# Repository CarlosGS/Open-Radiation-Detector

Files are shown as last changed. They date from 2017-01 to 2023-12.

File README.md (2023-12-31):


# Open Radiation Detector
Portable radiation detector based on a ionization chamber.

The KiCad PCB sources and BOM can be found in the repository's subfolders.

Check out <https://hackaday.io/project/27508-open-radiation-detector> for more information.

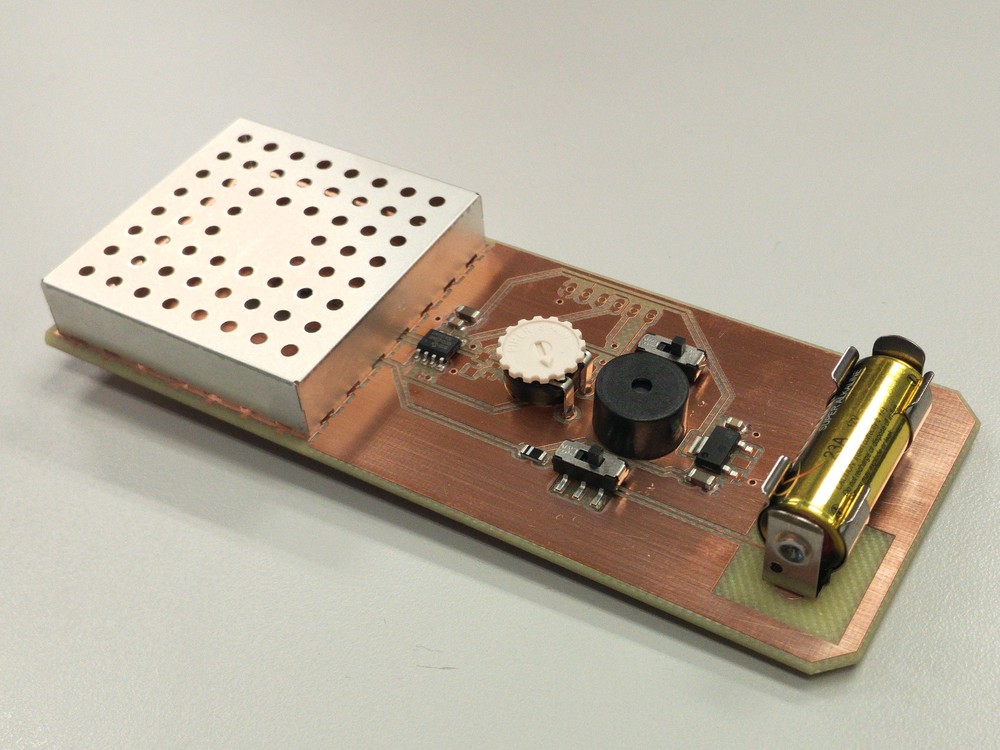
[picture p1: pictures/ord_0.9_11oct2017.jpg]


# Next version:
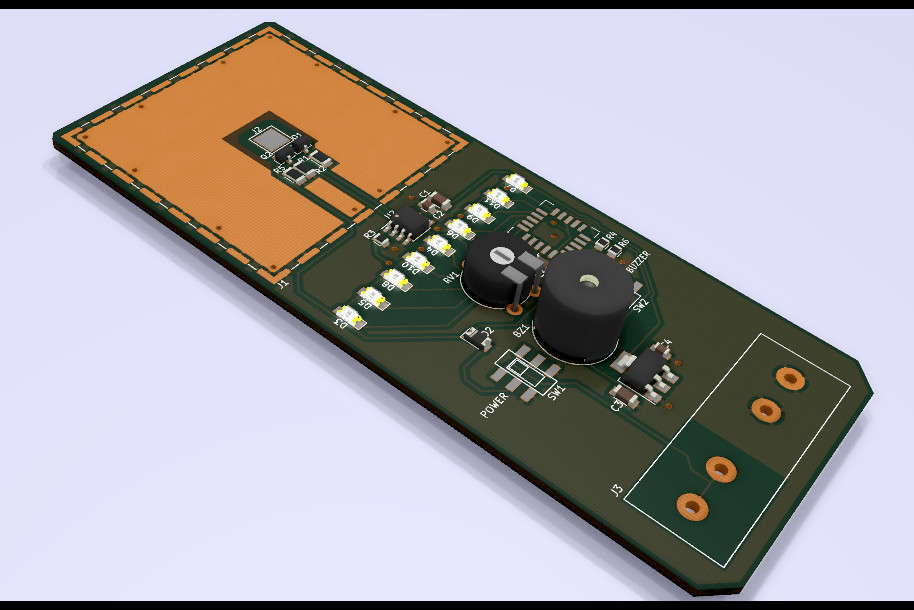
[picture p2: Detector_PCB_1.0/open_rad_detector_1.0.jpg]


# The detector works!
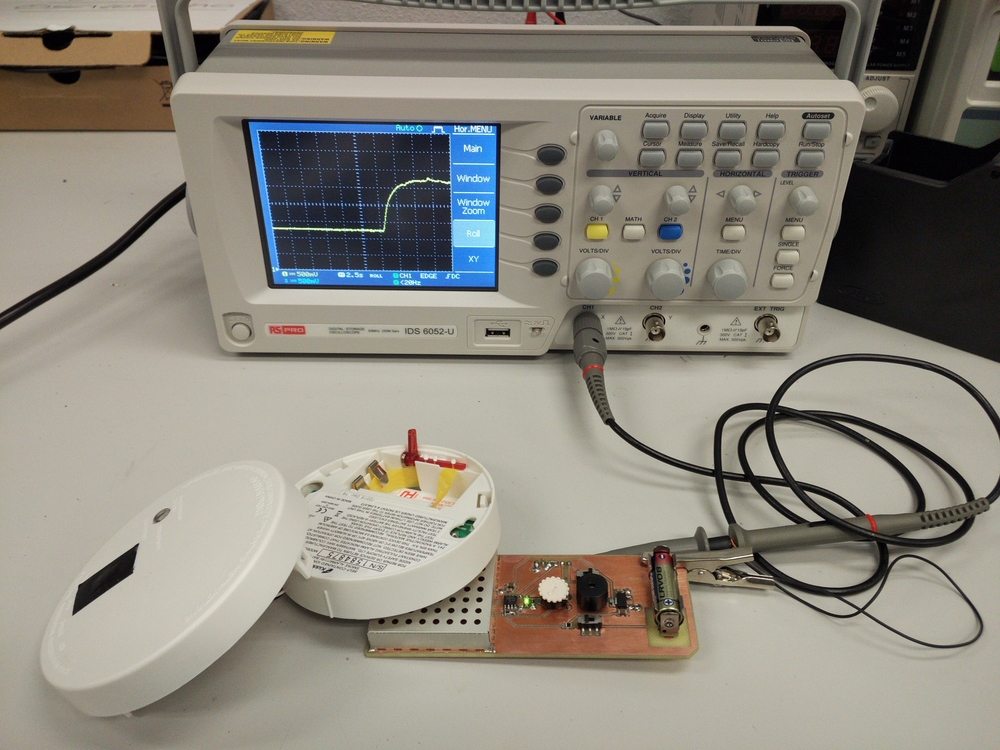
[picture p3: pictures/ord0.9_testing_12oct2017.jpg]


Progress
--
- October 2017: Designed, build and document a prototype to participate in the Hackaday Prize.

- 5/May/2017: The radiation sensor concept has been incorporated into a connected sensor board. It looks like the effect of nearby electrostatic fields still affects the voltage output, regardless of the back plane being connected to either guard voltage or ground (maybe this is due to the large size of the electrode?). The board uses the PNP configuration polarized with 10 MOhm 1% and an op-amp driver (LM2904DR) to minimize the effect of ADC current consumption. It includes a duplicate circuit unconnected from the electrode, to be used as a compensation for temperature effects.

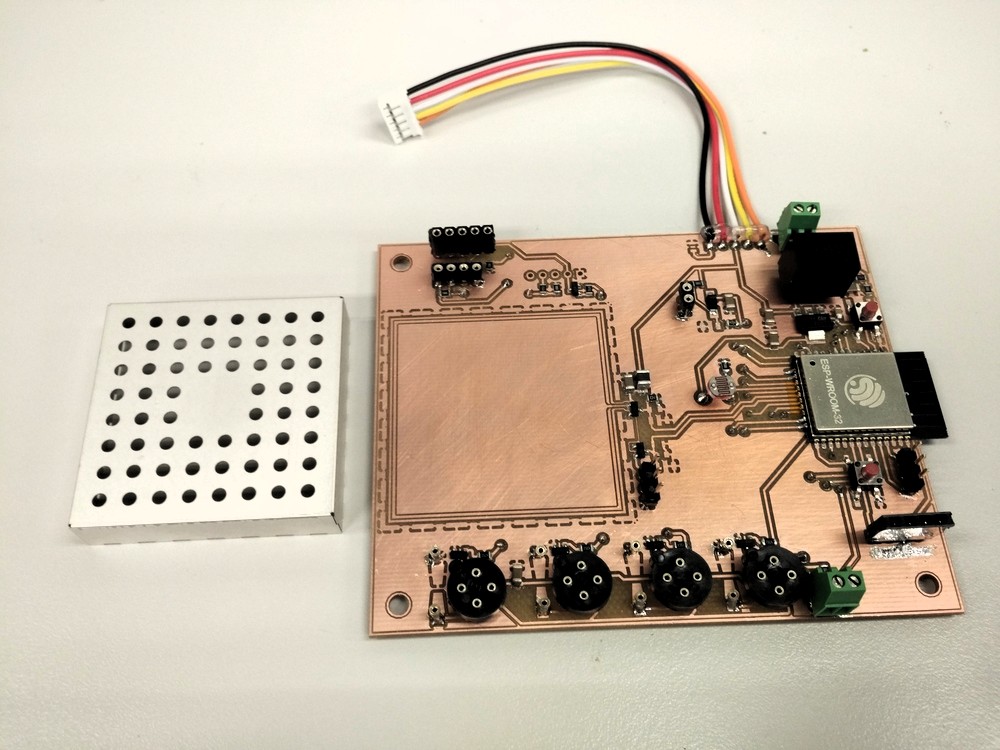
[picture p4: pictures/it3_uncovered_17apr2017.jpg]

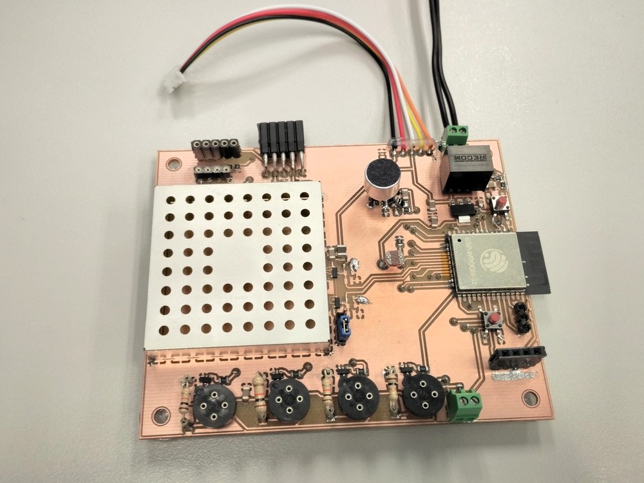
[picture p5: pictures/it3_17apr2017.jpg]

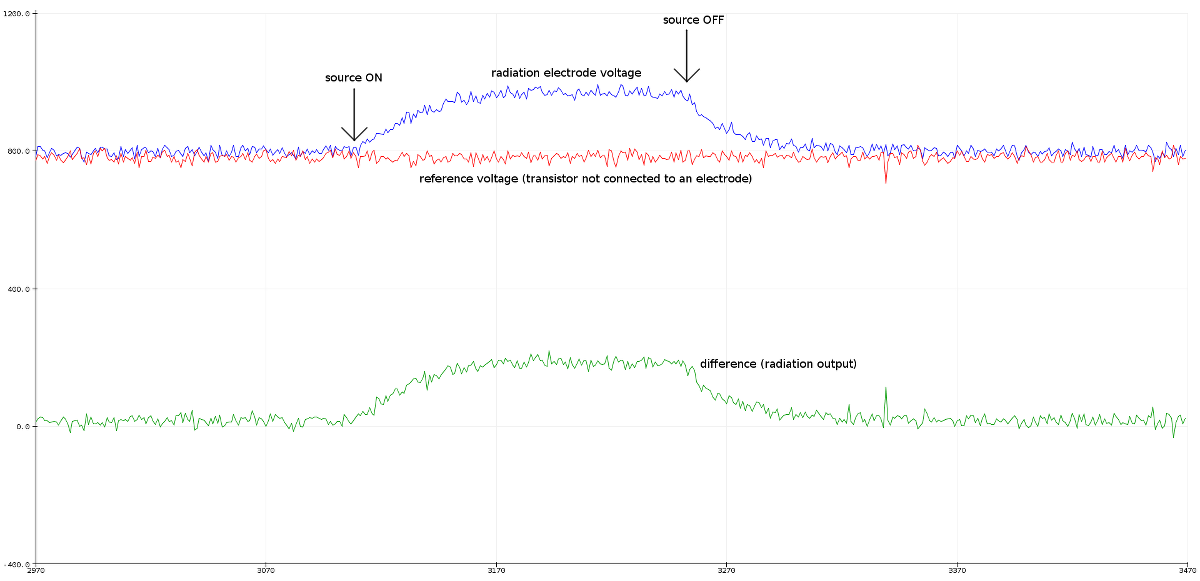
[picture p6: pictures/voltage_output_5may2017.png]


- 15/Feb/2017: It works! At first the result with the new transistors had lots of noise as well. But adding a copper plane behind the main electrode seems to have done the trick. So maybe the transistors were not the problem after all! The pictures show a new prototype being tested with and without a radiation source. Its response ranges from 70mV to 160mV and it is way more stable than before. Schematic is [Charles Wenzel's Experimenters Ionization Chamber](http://www.techlib.com/science/ion.html#Experimenters%20Chamber) with an FMMT634TA NPN darlington transistor.

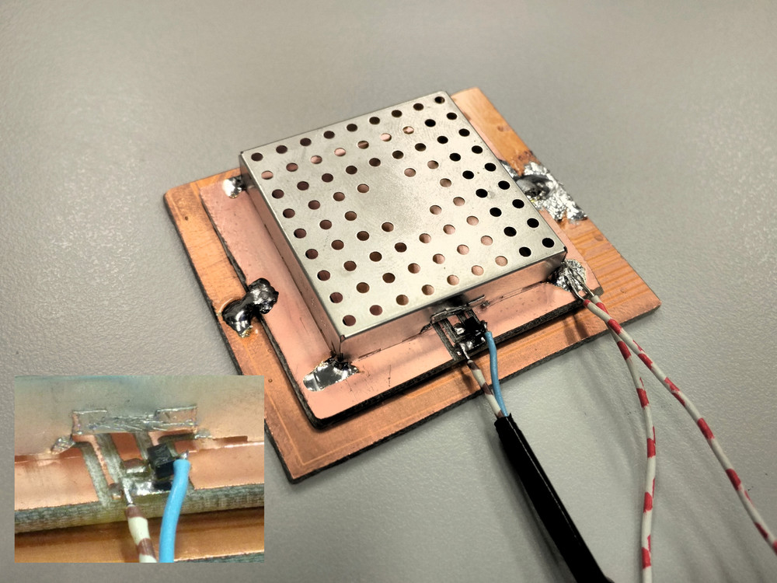
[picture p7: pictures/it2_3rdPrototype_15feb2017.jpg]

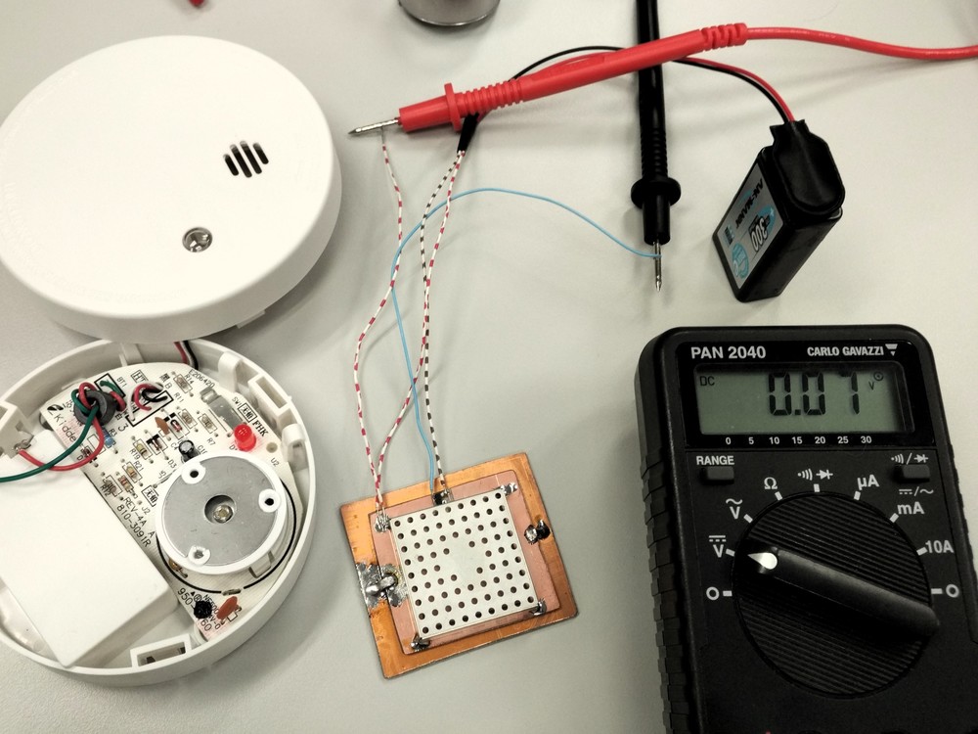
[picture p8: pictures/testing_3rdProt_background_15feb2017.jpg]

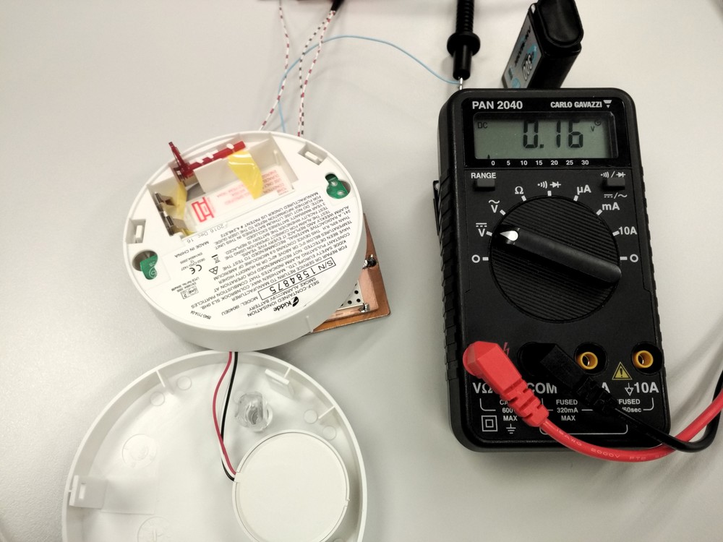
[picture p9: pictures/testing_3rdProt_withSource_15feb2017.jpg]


- 8/Feb/2017: The Darlington transistors used until now (MMBT6427, MMBTA14, MMBTA28, MMBTA63, MMBTA64) may not be suitable for detecting the low currents involved in this detection problem (nA or even pA). Yet again I have resorted to Charles Wenzel's awesome website. A proper surface-mount alternative to the MPSAW45A power darlington transistor may be the FMMT634 and FMMT734. So I've ordered a bunch of these transistors in order to test the concept again.

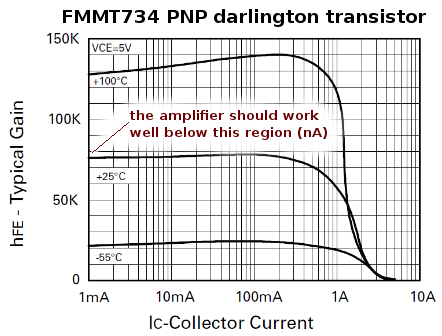
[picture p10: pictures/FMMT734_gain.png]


- Week of 7/Feb/2017: The new approach is to use an actual ion chamber that uses a copper electrode insulated from ground by an outer guard ring. The chamber itself is made of [a standard size, commercially available PCB shielding can](http://www.mouser.es/Search/ProductDetail.aspx?R=BMI-S-104virtualkey64820000virtualkey739-BMI-S-104) (in the pictures you can see my attempt at creating one with tin sheet from a metal can). The first prototype actually seemed to have some reaction during the tests. However the second prototype did not. [G-code to mill the electrode](http://jscut.org/jscut.html?gist=c962737e35c9f9b0445b82d079ceb10d).

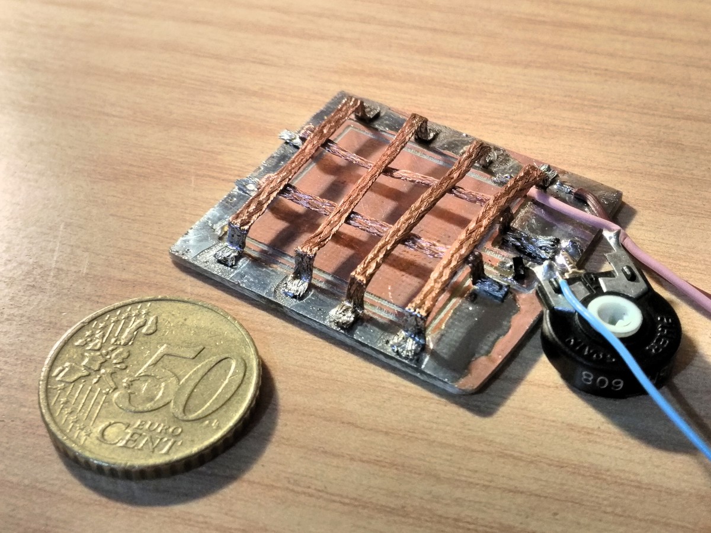
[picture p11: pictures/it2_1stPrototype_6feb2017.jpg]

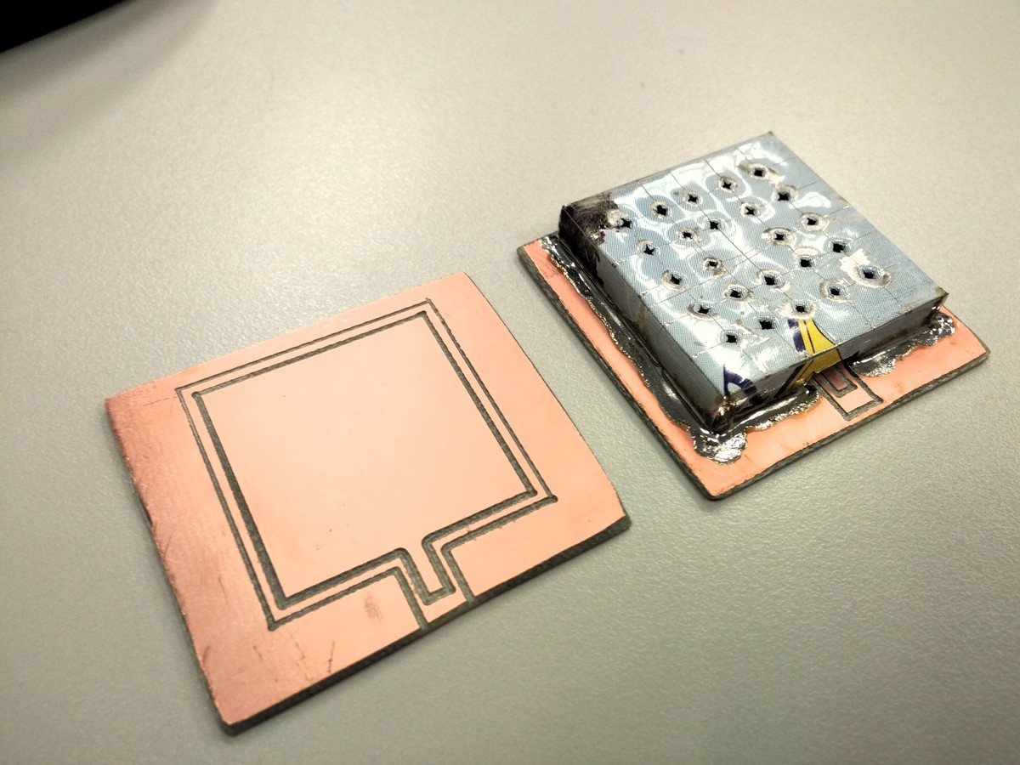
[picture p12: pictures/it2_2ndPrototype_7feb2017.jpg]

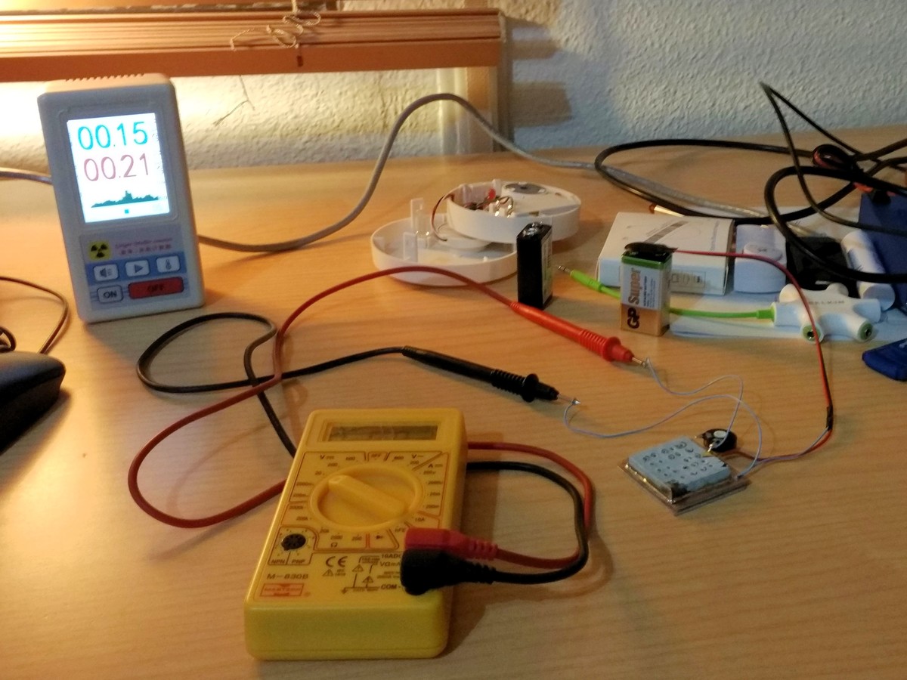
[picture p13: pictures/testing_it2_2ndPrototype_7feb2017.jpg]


- On a second thought, the "finger electrodes" may not be a good idea. Since there is a large contact area between each finger, there surely is a lot of leakage current that will mask-out any ion-induced current (one of the biggest concerns explained by [Charles Wenzel's ion chamber website](http://www.techlib.com/science/ion.html))

- 19/Jan/2017 Finally got a .9uCi AM241 source to test, it will be the benchmark for the detector. Unfortunately, the first attempts with the amplifier circuit yield very noisy measurements, that mainly depend on wind and humidity. Surprisingly (to me), it is also very dependent on static electricity. I've also tested again the spark particle detector, but there seems to be absolutely no relation between the sparks and the proximity of the radiation source. Maybe the finger electrodes are too "pointy" because of the manufacture method (milling)? [pic1](pictures/fingerElectrodeZoom1_19Jan2017.jpg) [pic2](pictures/fingerElectrodeZoom2_19Jan2017.jpg)

- Week of 9/Jan/2017: Simulation of circuit amplifiers ["click type"](http://lushprojects.com/circuitjs/circuitjs.html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), ["LED scale type"](http://lushprojects.com/circuitjs/circuitjs.html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)

- Self-ask the question: How to make a simple low-cost radiation detector? Begin to learn about ionization chambers thanks to [Charles Wenzel's website](http://www.techlib.com/science/ion.html).

- Week of 1/Jan/2017: First learn of spark particle detectors. [Design, build and test a PCB electrode](https://github.com/vlachoudis/bCNC/pull/480) (but without any radiation source to be tested). [video](https://www.youtube.com/watch?v=s3N2EDGwe9U)

# License
This work is licensed under a Creative Commons Attribution 4.0 International License.
<https://creativecommons.org/licenses/by/4.0/>

Please cite as:
--
Garcia-Saura, C. (2017). Open Radiation Detector. GitHub. https://doi.org/10.5281/ZENODO.10446305

Latex / Bibtex citation:
```bibtex
@misc{garciasaura2017rad,
  author = {Garcia-Saura, Carlos},
  title = {Open Radiation Detector},
  publisher = {GitHub},
  year = {2017},
  doi = {10.5281/ZENODO.10446305},
  url = {https://doi.org/10.5281/ZENODO.10446305}
}
```

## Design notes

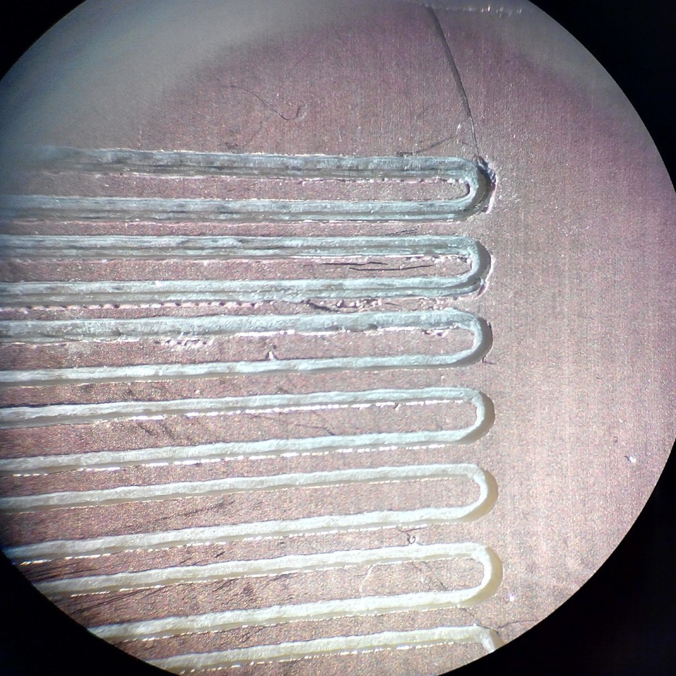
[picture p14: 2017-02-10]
pictures/fingerElectrodeZoom2_19Jan2017.jpg

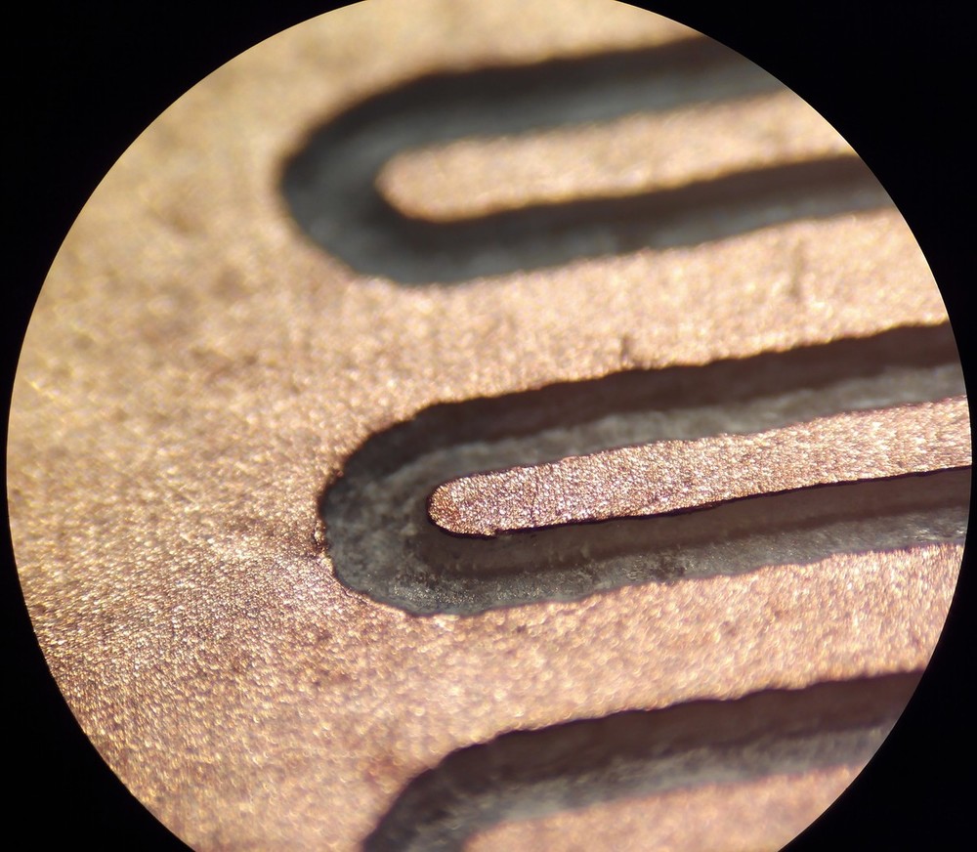
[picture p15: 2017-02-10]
pictures/fingerElectrodeZoom1_19Jan2017.jpg

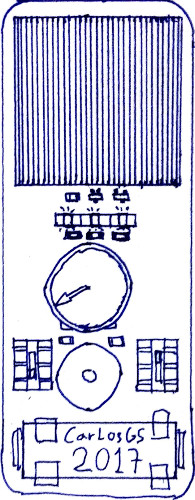
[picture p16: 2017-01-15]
pictures/ORD_sketch_15jan2017.jpg

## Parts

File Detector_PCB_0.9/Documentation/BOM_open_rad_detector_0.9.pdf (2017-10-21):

open_rad_detector

Page 1

Source | open-radiation-detector/Detector_PCB_0.9/open_rad_detector.sch
Title | Open Radiation Detector
Revision | 0,9
Author: Carlos Garcia Saura
License: Creative Commons Attribution-ShareAlike 4.0 International
https://creativecommons.org/licenses/by-sa/4.0/
https://hackaday.io/project/27508-open-radiation-detector/ | Total cost: | 14 | € | (bulk would be cheaper)
Reference | Value | Library | Library Ref | Manufacturer | Product ID | Provider | €/pc (17 oct 2017)
J1 | Outer_Shield | device | RF_Shield_One_Piece | Laird | BMI-S-107 | 3,9
BZ1 | Buzzer | device | Buzzer | Buzzer is not working yet. Please wait for the next version. | 1 | (link pending)
C1 | 10u | device | C | Vishay | VJ1206V106ZXQTW1B | 0,085 | (any other compatible is OK)
C2 | 100n | device | C | Vishay | VJ0805Y104JXXAC | 0,085 | (any other compatible is OK)
C3 | 10u | device | C | Vishay | VJ1206V106ZXQTW1B | 0,085 | (any other compatible is OK)
C4 | 100n | device | C | Vishay | VJ0805Y104JXXAC | 0,085 | (any other compatible is OK)
D1 | LED | device | LED | Lite-On | LTST-C150GKT | 0,315 | (any other compatible is OK)
D2 | D | device | D | AVX | SD1206S040S0R5 | 0,349 | (any other compatible is OK)
J2 | Electrode | conn | CONN_01X01 | AVX | 709176001511006 | 0,179 | Another option: | Mill-Max | 1944-0-00-15-00-00-03-0
J3 | Batt | conn | CONN_01X02 | Keystone Electronics | 82 | 0,76 | Need to buy 2 (two)
J4 | CONN_01X06 | conn | CONN_01X06 | Any connector of your choice
Q1 | FMMT734 | transistors | BC858 | Diodes Incorporated | FMMT734 | 0,476
Q2 | FMMT734 | transistors | BC858 | Diodes Incorporated | FMMT735 | 0,476
R1 | 10M | device | R | Vishay | CRCW120610M0FKEA | 0,085 | (any other compatible is OK)
R2 | 10M | device | R | Vishay | CRCW120610M0FKEA | 0,085 | (any other compatible is OK)
R3 | R_G | device | R | Vishay | CRCW08051K00FKEA | 0,085 | (any other compatible is OK)
R4 | R_LED | device | R | Vishay | CRCW0805330RFKEB | 0,085 | (any other compatible is OK)
R5 | 10M | device | R | Vishay | CRCW120610M0FKEA | 0,085 | (any other compatible is OK)
RV1 | R_F | device | POT | Piher | PT10MV10-104A2020 | 0,518
RV1 knob | Plastic knob for RV1 potentiometer | Piher | XBOPL5034CR | 0,227 | Hand mounted on potentiometer
SW1 | POWER | switches | SW_SPDT | C&K Components | JS202011SCQN | 0,374
SW2 | BUZZER | switches | SW_SPDT | C&K Components | JS202011SCQN | 0,374
U1 | LD1117S50TR | regul | LD1117S50TR | STMicroelectronics | LD1117S50TR | 0,383
U2 | MCP6N11 | MCP6N11 | MCP6N11 | Microchip Technology | MCP6N11-010E/SN | 1,26
Battery | Any A23 battery (12V), widely available in many stores | 2

http://www.mouser.es/ProductDetail/Laird/BMI-S-107/?qs=5UmOb8GQ3yLqc%2FnmGxIDzQ%3D%3D

http://www.mouser.es/ProductDetail/Vishay-Vitramon/VJ1206V106ZXQTW1BC/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 http://www.mouser.es/Search/ProductDetail.aspx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

http://www.mouser.es/ProductDetail/Diodes-Incorporated/FMMT734TA/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

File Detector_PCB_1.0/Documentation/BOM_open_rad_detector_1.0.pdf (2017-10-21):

open_rad_detector_BOM

Page 1

Source: open-radiation-detector/Detector_PCB_1.0/open_rad_detector.sch

Component C 34
Ref | Qnty | Value | Cmp name | Description | Manufacturer | Product ID | Provider | €/pc (17 oct 2017)
BZ1, | 1 Buzzer | Buzzer | Buzzer, polar
C1, C3, C5, | 3 10u | C | Unpolarized capacitor | Vishay | VJ1206V106ZXQTW1BC | 0,085 | (any other compatible is OK) (http://www.mouser.es/ProductDetail/Vishay-Vitramon/VJ1206V106ZXQTW1BC/?qs=DuJGCc1rRdTfUSwbrOLWgg)
C2, C4, | 2 100n | C | Unpolarized capacitor | Vishay | VJ0805Y104JXXAC | 0,085 | (any other compatible is OK) (http://www.mouser.es/ProductDetail/Vishay/VJ0805Y104JXXAC/)
D2, | 1 D | D | Diode | AVX | SD1206S040S0R5 | 0,349 | (any other compatible is OK) (http://www.mouser.es/ProductDetail/AVX/SD1206S040S0R5/)
D3, D5, D8, D | 9 LED | LED | LED generic | Lite-On | LTST-C150GKT | 0,315 | (any other compatible is OK) (https://www.mouser.es/ProductDetail/Lite-On/LTST-C150GKT/)
IC1, | 1 LM3914V | LM3914V
J1, | 1 Outer_ShieRF_Shield_OnOne-Piece EMI RF ShielLaird | BMI-S-107 | 3,9 (http://www.mouser.es/ProductDetail/Laird/BMI-S-107/?qs=5UmOb8GQ3yLqc%2FnmGxIDzQ%3D%3D)
J2, | 1 Electrode | Conn_01x01 | Generic connector, sing AVX | 709176001511006 | 0,179 | Another optionMill-Max | 1944-0-00-15-00-00-03-0 (http://www.mouser.es/Search/ProductDetail.aspx)
J3, | 1 Batt | Conn_01x02 | Generic connector, single row, 01x02
L1, | 1 33u | L | Inductor
Q1, Q2, | 2 FMMT734 BC858 | 45V Vce, 0.8A Ic, PNP, | Diodes Incorporated | FMMT734 | 0,476 (http://www.mouser.es/ProductDetail/Diodes-Incorporated/FMMT734TA/)
R1, R2, | 2 10M | R | Resistor | Vishay | CRCW120610M0FKEA | 0,085 | (any other compatible is OK) (http://www.mouser.es/ProductDetail/Vishay/CRCW120610M0FKEA/?qs=sGAEpiMZZMu61qfTUdNhG2DpbjADlD3G4GlZK7F654o%3D)
R3, | 1 R_G | R | Resistor | Vishay | CRCW08051K00FKEA | 0,085 | (any other compatible is OK) (http://www.mouser.es/ProductDetail/Vishay/CRCW08051K00FKEA/?qs=sGAEpiMZZMu61qfTUdNhG2DpbjADlD3GcHbGwBGgzyI%3D)
R4, | 1 LMR1 | R | Resistor
R5, | 1 Rtune | R | Resistor | Not placed (use to tune amplifier offset if needed)
R6, | 1 LMR2 | R | Resistor
RV1, | 1 R_F | POT | Potentiometer | Piher | PT10MV10-104A2020 | 0,518 (http://www.mouser.es/Search/ProductDetail.aspx)
SW1, | 1 POWER | SW_SPDT | Switch, single pole doubC&K Components | JS202011SCQN | 0,374 (http://www.mouser.es/ProductDetail/CK-Components/JS202011SCQN/)
SW2, | 1 BUZZER | SW_SPDT | Switch, single pole doubC&K Components | JS202011SCQN | 0,374 (http://www.mouser.es/ProductDetail/CK-Components/JS202011SCQN/)
U1, | 1 LD1117S5LD1117S50T 1A Low Dropout regulatorSTMicroelectronics | LD1117S50TR | 0,383 (http://www.mouser.es/ProductDetail/STMicroelectronics/LD1117S50TR/)
U2, | 1 MCP6N11 MCP6N11 | Instrumentation Amplifi | Microchip Technology | MCP6N11-010E/SN | 1,26 (http://www.mouser.es/ProductDetail/Microchip-Technology/MCP6N11-010E-SN/?qs=sGAEpiMZZMsxjDnzDDgGYPCqhVo3A%2FsQ)

http://www.mouser.es/ProductDetail/Vishay-Vitramon/VJ1206V106ZXQTW1BC/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

http://www.mouser.es/ProductDetail/Laird/BMI-S-107/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 http://www.mouser.es/Search/ProductDetail.aspx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

http://www.mouser.es/ProductDetail/Diodes-Incorporated/FMMT734TA/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

http://www.mouser.es/Search/ProductDetail.aspx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

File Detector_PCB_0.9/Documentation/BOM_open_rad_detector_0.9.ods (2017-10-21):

Source | open-radiation-detector/Detector_PCB_0.9/open_rad_detector.sch
Title | Open Radiation Detector
Revision | 0,9
 | Author: Carlos Garcia Saura
 | License: Creative Commons Attribution-ShareAlike 4.0 International
 | https://creativecommons.org/licenses/by-sa/4.0/
 | https://hackaday.io/project/27508-open-radiation-detector/ |  |  |  |  | Total cost: | 14 | € | (bulk would be cheaper)
Reference | Value | Library | Library Ref | Manufacturer | Product ID | Provider | €/pc (17 oct 2017)
J1 | Outer_Shield | device | RF_Shield_One_Piece | Laird | BMI-S-107 | http://www.mouser.es/ProductDetail/Laird/BMI-S-107/?qs=5UmOb8GQ3yLqc%2FnmGxIDzQ%3D%3D | 3,9
BZ1 | Buzzer | device | Buzzer | Buzzer is not working yet. Please wait for the next version. |  |  | 1 | (link pending)
C1 | 10u | device | C | Vishay | VJ1206V106ZXQTW1BC | http://www.mouser.es/ProductDetail/Vishay-Vitramon/VJ1206V106ZXQTW1BC/?qs=DuJGCc1rRdTfUSwbrOLWgg== | 0,085 | (any other compatible is OK)
C2 | 100n | device | C | Vishay | VJ0805Y104JXXAC | http://www.mouser.es/ProductDetail/Vishay/VJ0805Y104JXXAC/ | 0,085 | (any other compatible is OK)
C3 | 10u | device | C | Vishay | VJ1206V106ZXQTW1BC | http://www.mouser.es/ProductDetail/Vishay-Vitramon/VJ1206V106ZXQTW1BC/?qs=DuJGCc1rRdTfUSwbrOLWgg== | 0,085 | (any other compatible is OK)
C4 | 100n | device | C | Vishay | VJ0805Y104JXXAC | http://www.mouser.es/ProductDetail/Vishay/VJ0805Y104JXXAC/ | 0,085 | (any other compatible is OK)
D1 | LED | device | LED | Lite-On | LTST-C150GKT | https://www.mouser.es/ProductDetail/Lite-On/LTST-C150GKT/ | 0,315 | (any other compatible is OK)
D2 | D | device | D | AVX | SD1206S040S0R5 | http://www.mouser.es/ProductDetail/AVX/SD1206S040S0R5/ | 0,349 | (any other compatible is OK)
J2 | Electrode | conn | CONN_01X01 | AVX | 709176001511006 | http://www.mouser.es/Search/ProductDetail.aspx | 0,179 | Another option: | Mill-Max | http://www.mouser.es/Search/ProductDetail.aspx | 1944-0-00-15-00-00-03-0
J3 | Batt | conn | CONN_01X02 | Keystone Electronics | 82 | http://www.mouser.es/Search/ProductDetail.aspx?R=82virtualkey53400000virtualkey534-082 | 0,76 | Need to buy 2 (two)
J4 | CONN_01X06 | conn | CONN_01X06 |  |  |  |  | Any connector of your choice
Q1 | FMMT734 | transistors | BC858 | Diodes Incorporated | FMMT734 | http://www.mouser.es/ProductDetail/Diodes-Incorporated/FMMT734TA/ | 0,476
Q2 | FMMT734 | transistors | BC858 | Diodes Incorporated | FMMT735 | http://www.mouser.es/ProductDetail/Diodes-Incorporated/FMMT734TA/ | 0,476
R1 | 10M | device | R | Vishay | CRCW120610M0FKEA | http://www.mouser.es/ProductDetail/Vishay/CRCW120610M0FKEA/?qs=sGAEpiMZZMu61qfTUdNhG2DpbjADlD3G4GlZK7F654o%3d | 0,085 | (any other compatible is OK)
R2 | 10M | device | R | Vishay | CRCW120610M0FKEA | http://www.mouser.es/ProductDetail/Vishay/CRCW120610M0FKEA/?qs=sGAEpiMZZMu61qfTUdNhG2DpbjADlD3G4GlZK7F654o%3d | 0,085 | (any other compatible is OK)
R3 | R_G | device | R | Vishay | CRCW08051K00FKEA | http://www.mouser.es/ProductDetail/Vishay/CRCW08051K00FKEA/?qs=sGAEpiMZZMu61qfTUdNhG2DpbjADlD3GcHbGwBGgzyI%3d | 0,085 | (any other compatible is OK)
R4 | R_LED | device | R | Vishay | CRCW0805330RFKEB | https://www.mouser.es/Search/ProductDetail.aspx | 0,085 | (any other compatible is OK)
R5 | 10M | device | R | Vishay | CRCW120610M0FKEA | http://www.mouser.es/ProductDetail/Vishay/CRCW120610M0FKEA/?qs=sGAEpiMZZMu61qfTUdNhG2DpbjADlD3G4GlZK7F654o%3d | 0,085 | (any other compatible is OK)
RV1 | R_F | device | POT | Piher | PT10MV10-104A2020 | http://www.mouser.es/Search/ProductDetail.aspx | 0,518
RV1 knob | Plastic knob for RV1 potentiometer |  |  | Piher | XBOPL5034CR | http://www.mouser.es/Search/ProductDetail.aspx | 0,227 | Hand mounted on potentiometer
SW1 | POWER | switches | SW_SPDT | C&K Components | JS202011SCQN | http://www.mouser.es/ProductDetail/CK-Components/JS202011SCQN/ | 0,374
SW2 | BUZZER | switches | SW_SPDT | C&K Components | JS202011SCQN | http://www.mouser.es/ProductDetail/CK-Components/JS202011SCQN/ | 0,374
U1 | LD1117S50TR | regul | LD1117S50TR | STMicroelectronics | LD1117S50TR | http://www.mouser.es/ProductDetail/STMicroelectronics/LD1117S50TR/ | 0,383
U2 | MCP6N11 | MCP6N11 | MCP6N11 | Microchip Technology | MCP6N11-010E/SN | http://www.mouser.es/ProductDetail/Microchip-Technology/MCP6N11-010E-SN/?qs=sGAEpiMZZMsxjDnzDDgGYPCqhVo3A%2fsQ | 1,26
 | Battery |  |  | Any A23 battery (12V), widely available in many stores |  |  | 2

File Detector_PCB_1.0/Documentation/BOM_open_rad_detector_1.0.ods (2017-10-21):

Source: | open-radiation-detector/Detector_PCB_1.0/open_rad_detector.sch
Component Count: | 34
Ref | Qnty | Value | Cmp name | Description | Manufacturer | Product ID | Provider | €/pc (17 oct 2017)
BZ1, | 1 | Buzzer | Buzzer | Buzzer, polar
C1, C3, C5, | 3 | 10u | C | Unpolarized capacitor | Vishay | VJ1206V106ZXQTW1BC | http://www.mouser.es/ProductDetail/Vishay-Vitramon/VJ1206V106ZXQTW1BC/?qs=DuJGCc1rRdTfUSwbrOLWgg== | 0,085 | (any other compatible is OK)
C2, C4, | 2 | 100n | C | Unpolarized capacitor | Vishay | VJ0805Y104JXXAC | http://www.mouser.es/ProductDetail/Vishay/VJ0805Y104JXXAC/ | 0,085 | (any other compatible is OK)
D2, | 1 | D | D | Diode | AVX | SD1206S040S0R5 | http://www.mouser.es/ProductDetail/AVX/SD1206S040S0R5/ | 0,349 | (any other compatible is OK)
D3, D5, D8, D10, D4, D6, D9, D11, D7, | 9 | LED | LED | LED generic | Lite-On | LTST-C150GKT | https://www.mouser.es/ProductDetail/Lite-On/LTST-C150GKT/ | 0,315 | (any other compatible is OK)
IC1, | 1 | LM3914V | LM3914V
J1, | 1 | Outer_Shield | RF_Shield_One_Piece | One-Piece EMI RF Shielding Cabinet | Laird | BMI-S-107 | http://www.mouser.es/ProductDetail/Laird/BMI-S-107/?qs=5UmOb8GQ3yLqc%2FnmGxIDzQ%3D%3D | 3,9
J2, | 1 | Electrode | Conn_01x01 | Generic connector, single row, 01x01 | AVX | 709176001511006 | http://www.mouser.es/Search/ProductDetail.aspx | 0,179 | Another option: | Mill-Max | http://www.mouser.es/Search/ProductDetail.aspx | 1944-0-00-15-00-00-03-0
J3, | 1 | Batt | Conn_01x02 | Generic connector, single row, 01x02
L1, | 1 | 33u | L | Inductor
Q1, Q2, | 2 | FMMT734 | BC858 | 45V Vce, 0.8A Ic, PNP, SOT-23 | Diodes Incorporated | FMMT734 | http://www.mouser.es/ProductDetail/Diodes-Incorporated/FMMT734TA/ | 0,476
R1, R2, | 2 | 10M | R | Resistor | Vishay | CRCW120610M0FKEA | http://www.mouser.es/ProductDetail/Vishay/CRCW120610M0FKEA/?qs=sGAEpiMZZMu61qfTUdNhG2DpbjADlD3G4GlZK7F654o%3d | 0,085 | (any other compatible is OK)
R3, | 1 | R_G | R | Resistor | Vishay | CRCW08051K00FKEA | http://www.mouser.es/ProductDetail/Vishay/CRCW08051K00FKEA/?qs=sGAEpiMZZMu61qfTUdNhG2DpbjADlD3GcHbGwBGgzyI%3d | 0,085 | (any other compatible is OK)
R4, | 1 | LMR1 | R | Resistor
R5, | 1 | Rtune | R | Resistor | Not placed (use to tune amplifier offset if needed)
R6, | 1 | LMR2 | R | Resistor
RV1, | 1 | R_F | POT | Potentiometer | Piher | PT10MV10-104A2020 | http://www.mouser.es/Search/ProductDetail.aspx | 0,518
SW1, | 1 | POWER | SW_SPDT | Switch, single pole double throw | C&K Components | JS202011SCQN | http://www.mouser.es/ProductDetail/CK-Components/JS202011SCQN/ | 0,374
SW2, | 1 | BUZZER | SW_SPDT | Switch, single pole double throw | C&K Components | JS202011SCQN | http://www.mouser.es/ProductDetail/CK-Components/JS202011SCQN/ | 0,374
U1, | 1 | LD1117S50TR_SOT223 | LD1117S50TR_SOT223 | 1A Low Dropout regulator, positive, 1.5V fixed output, SOT-223 | STMicroelectronics | LD1117S50TR | http://www.mouser.es/ProductDetail/STMicroelectronics/LD1117S50TR/ | 0,383
U2, | 1 | MCP6N11 | MCP6N11 | Instrumentation Amplifiers Sin, 500kHz, 800uA Gmin 10 v/v | Microchip Technology | MCP6N11-010E/SN | http://www.mouser.es/ProductDetail/Microchip-Technology/MCP6N11-010E-SN/?qs=sGAEpiMZZMsxjDnzDDgGYPCqhVo3A%2fsQ | 1,26

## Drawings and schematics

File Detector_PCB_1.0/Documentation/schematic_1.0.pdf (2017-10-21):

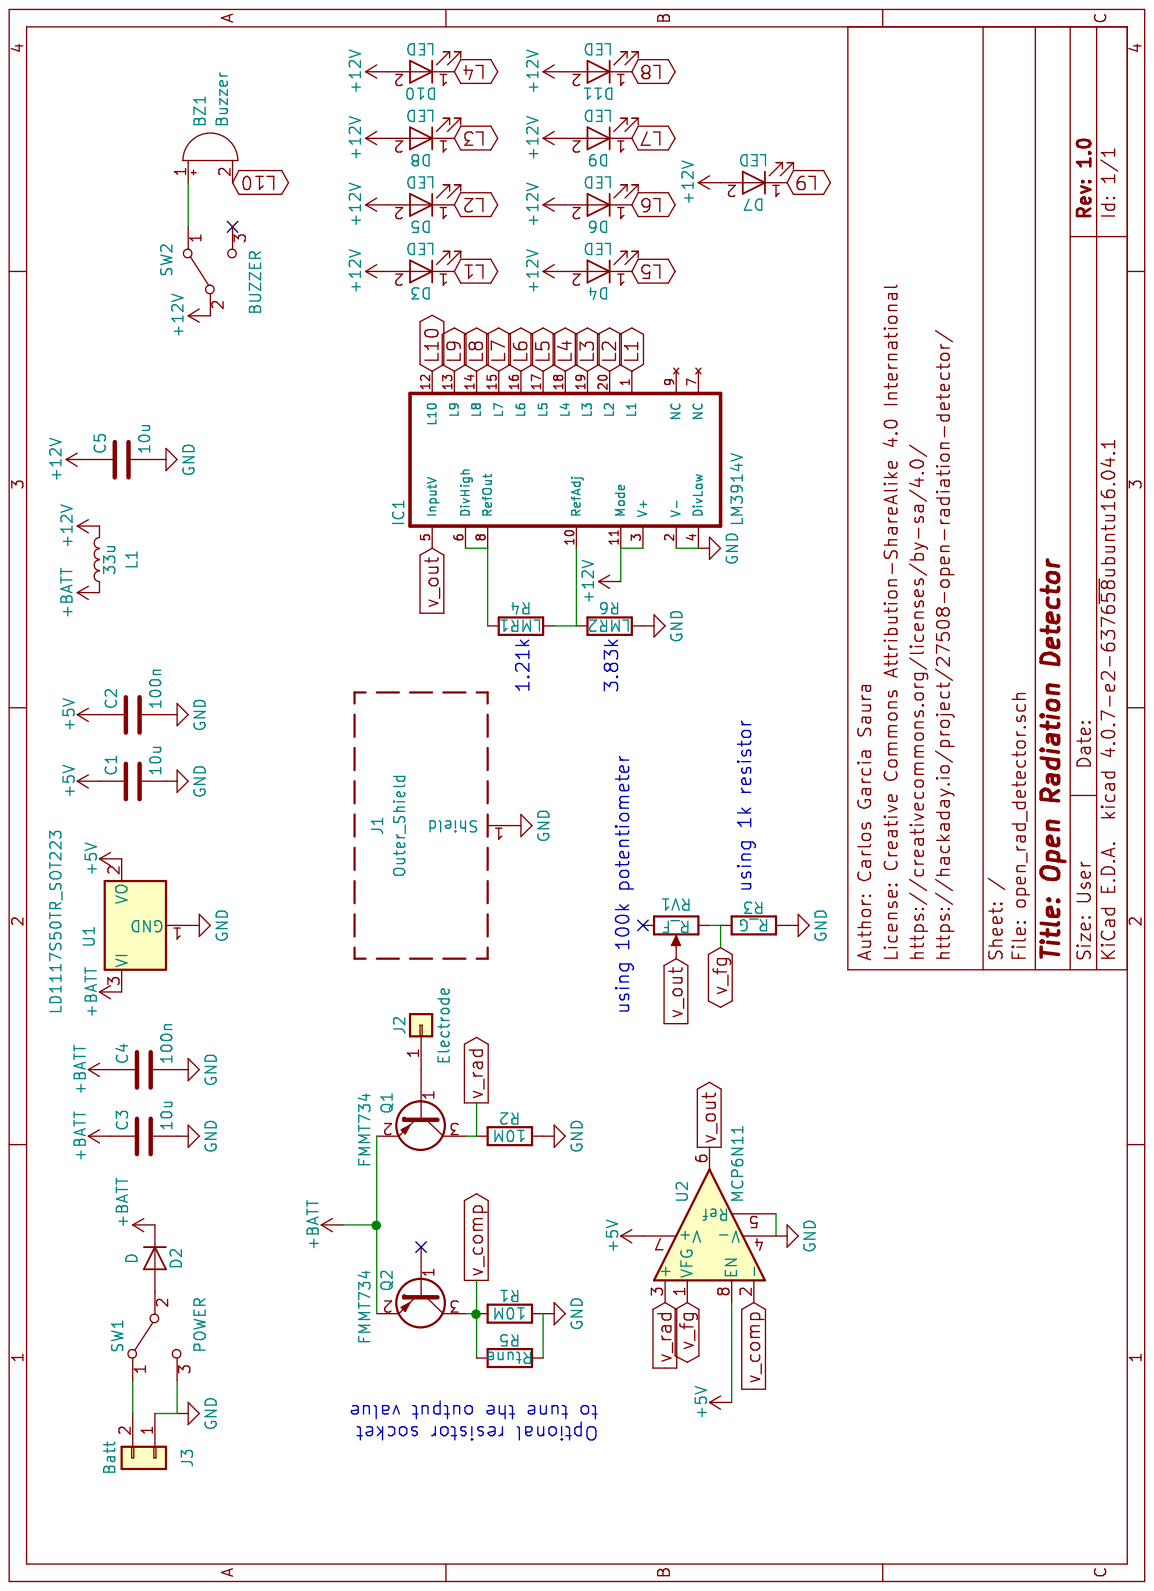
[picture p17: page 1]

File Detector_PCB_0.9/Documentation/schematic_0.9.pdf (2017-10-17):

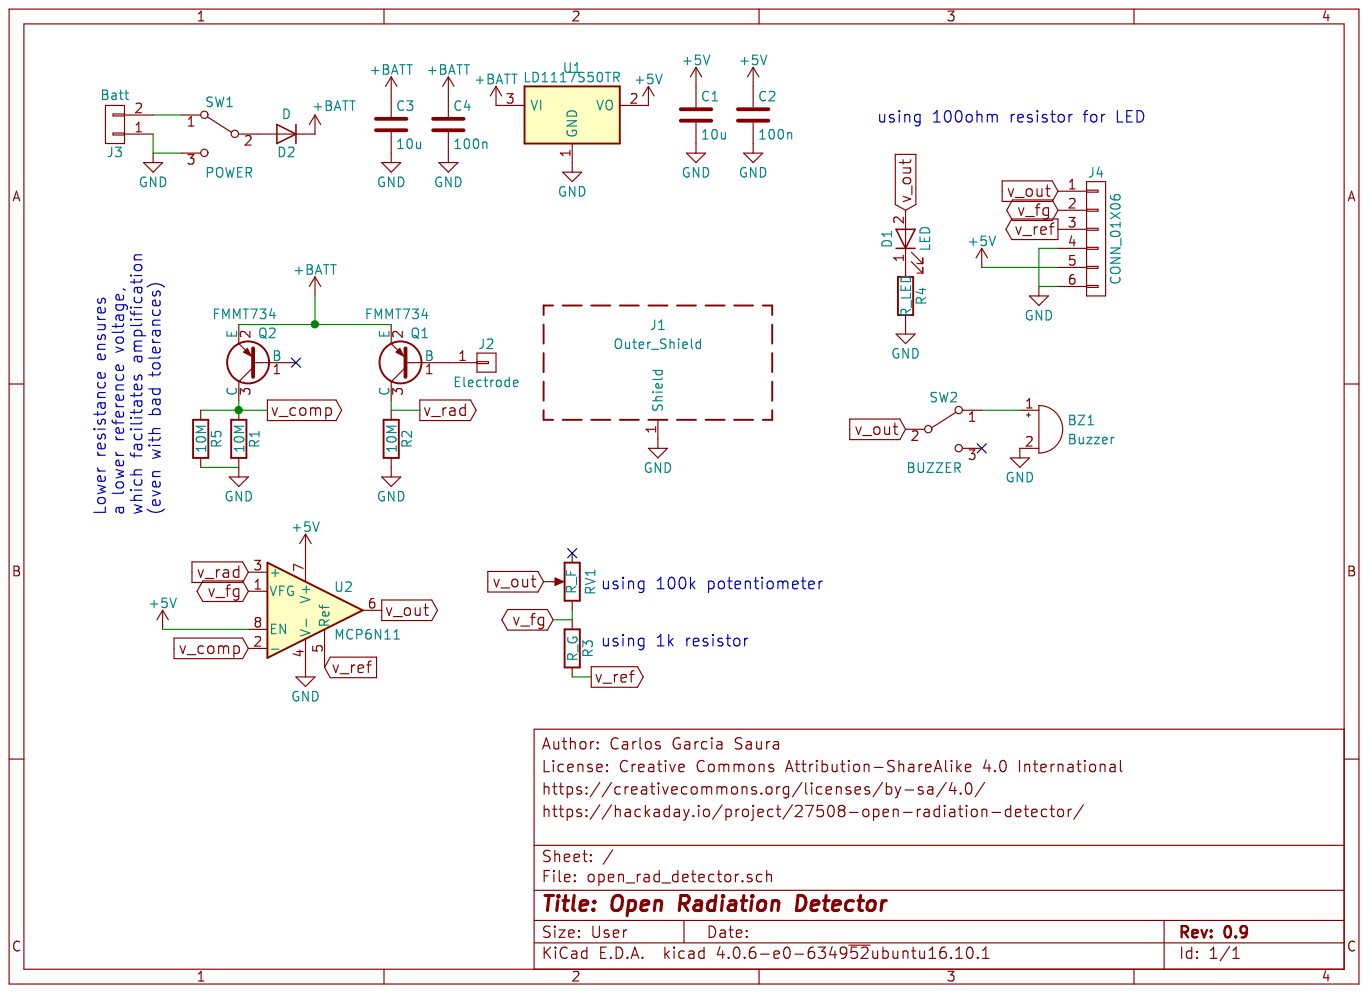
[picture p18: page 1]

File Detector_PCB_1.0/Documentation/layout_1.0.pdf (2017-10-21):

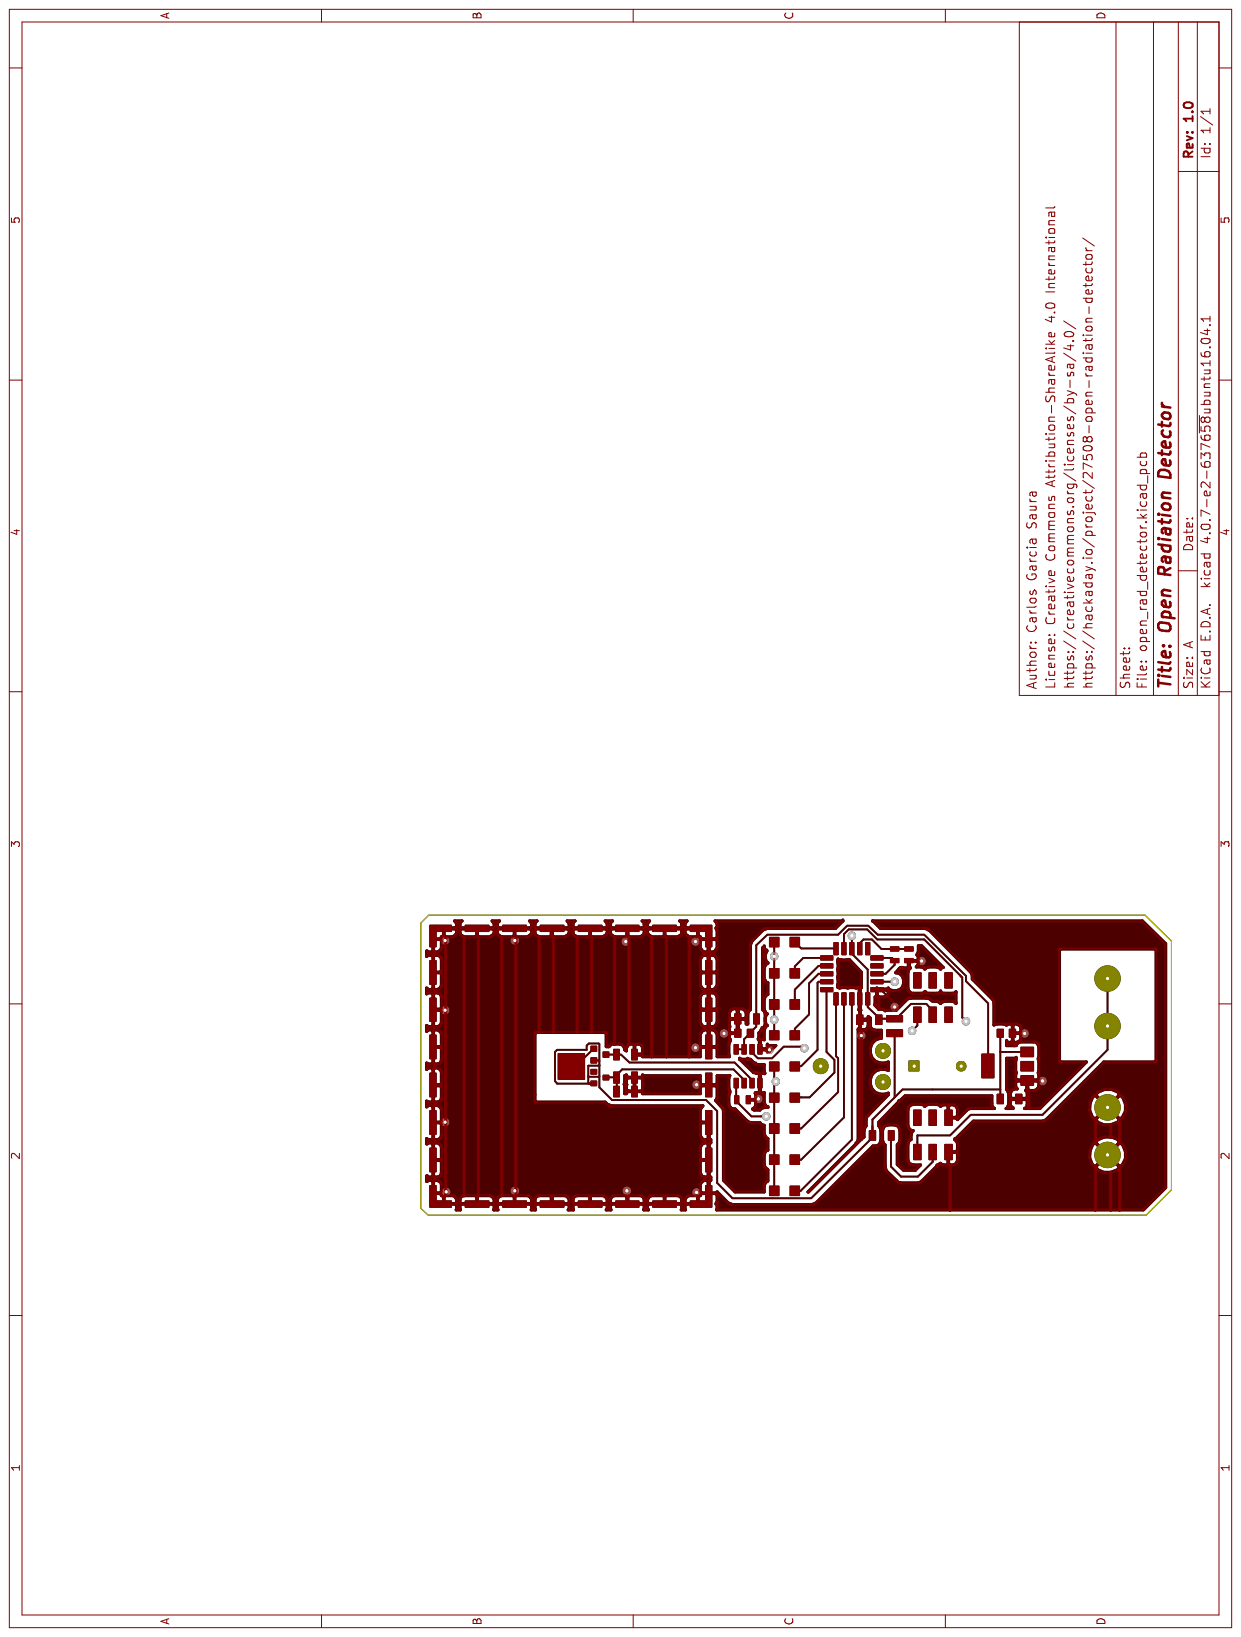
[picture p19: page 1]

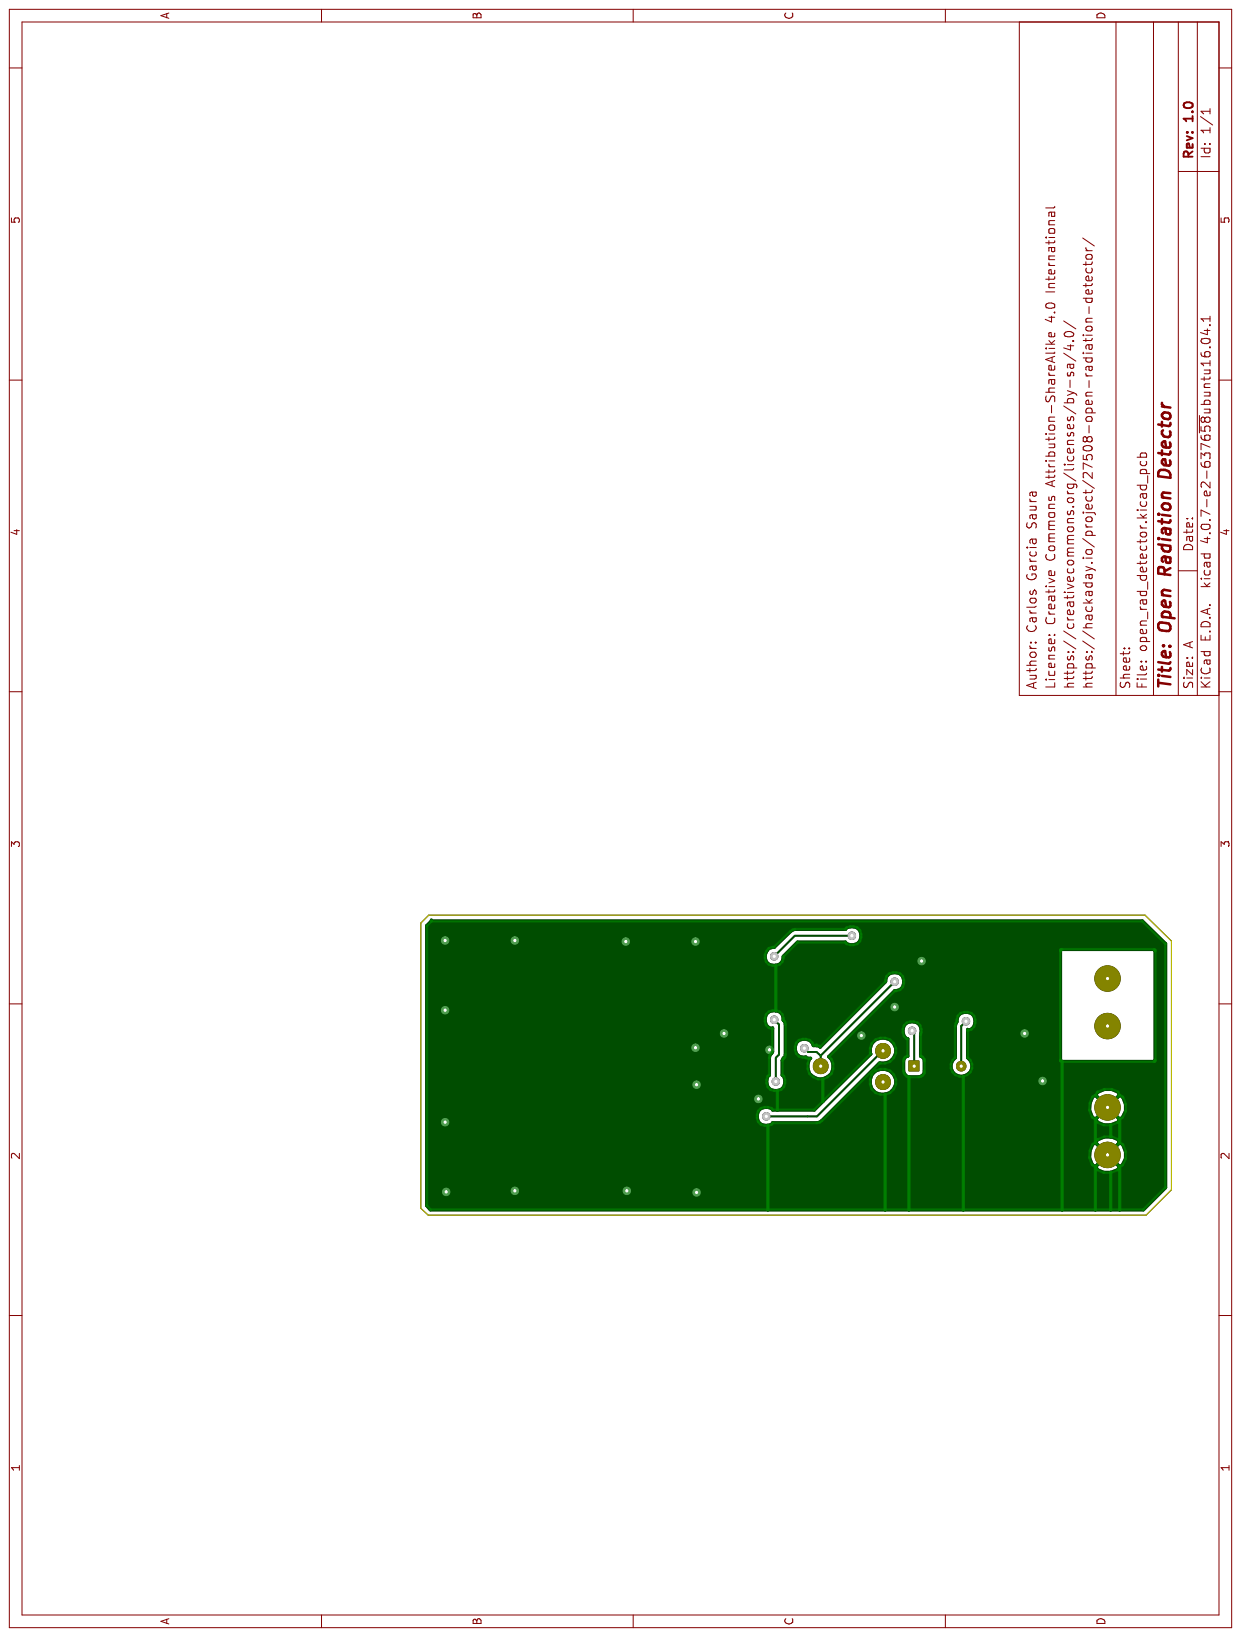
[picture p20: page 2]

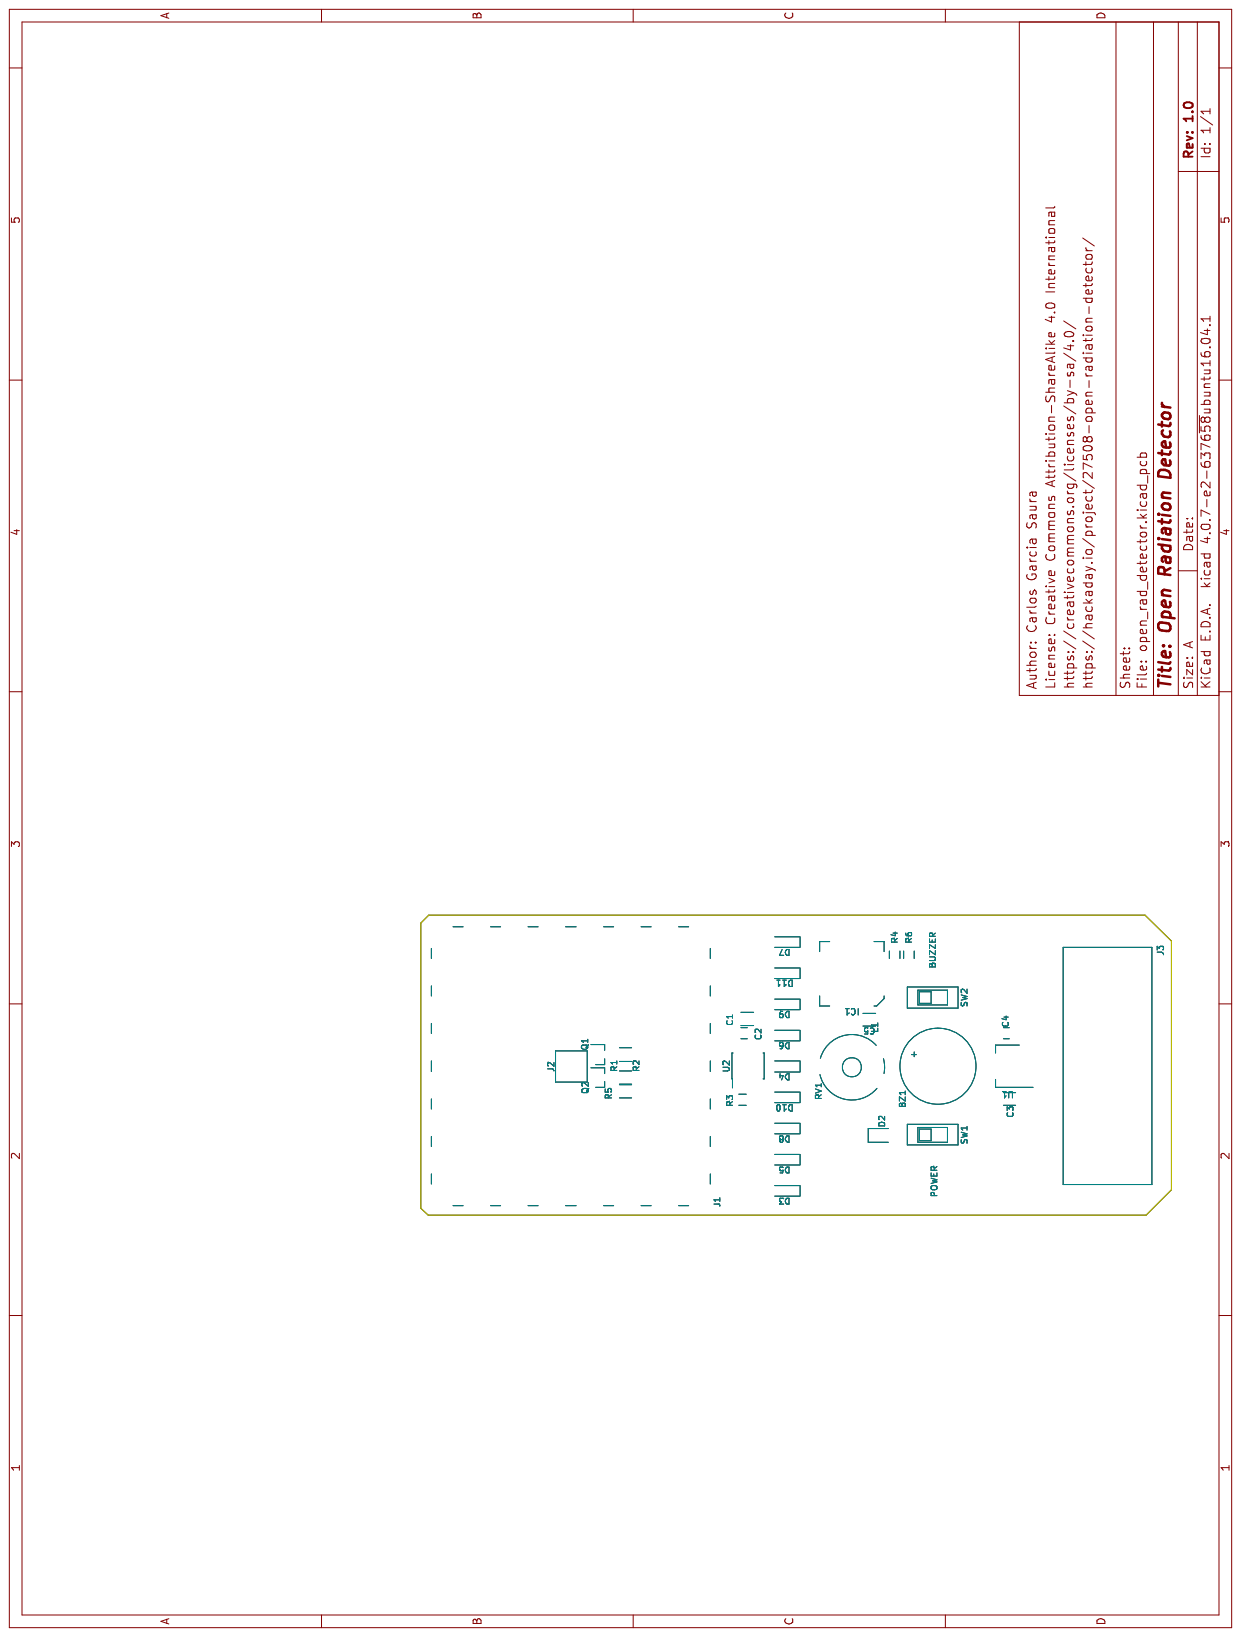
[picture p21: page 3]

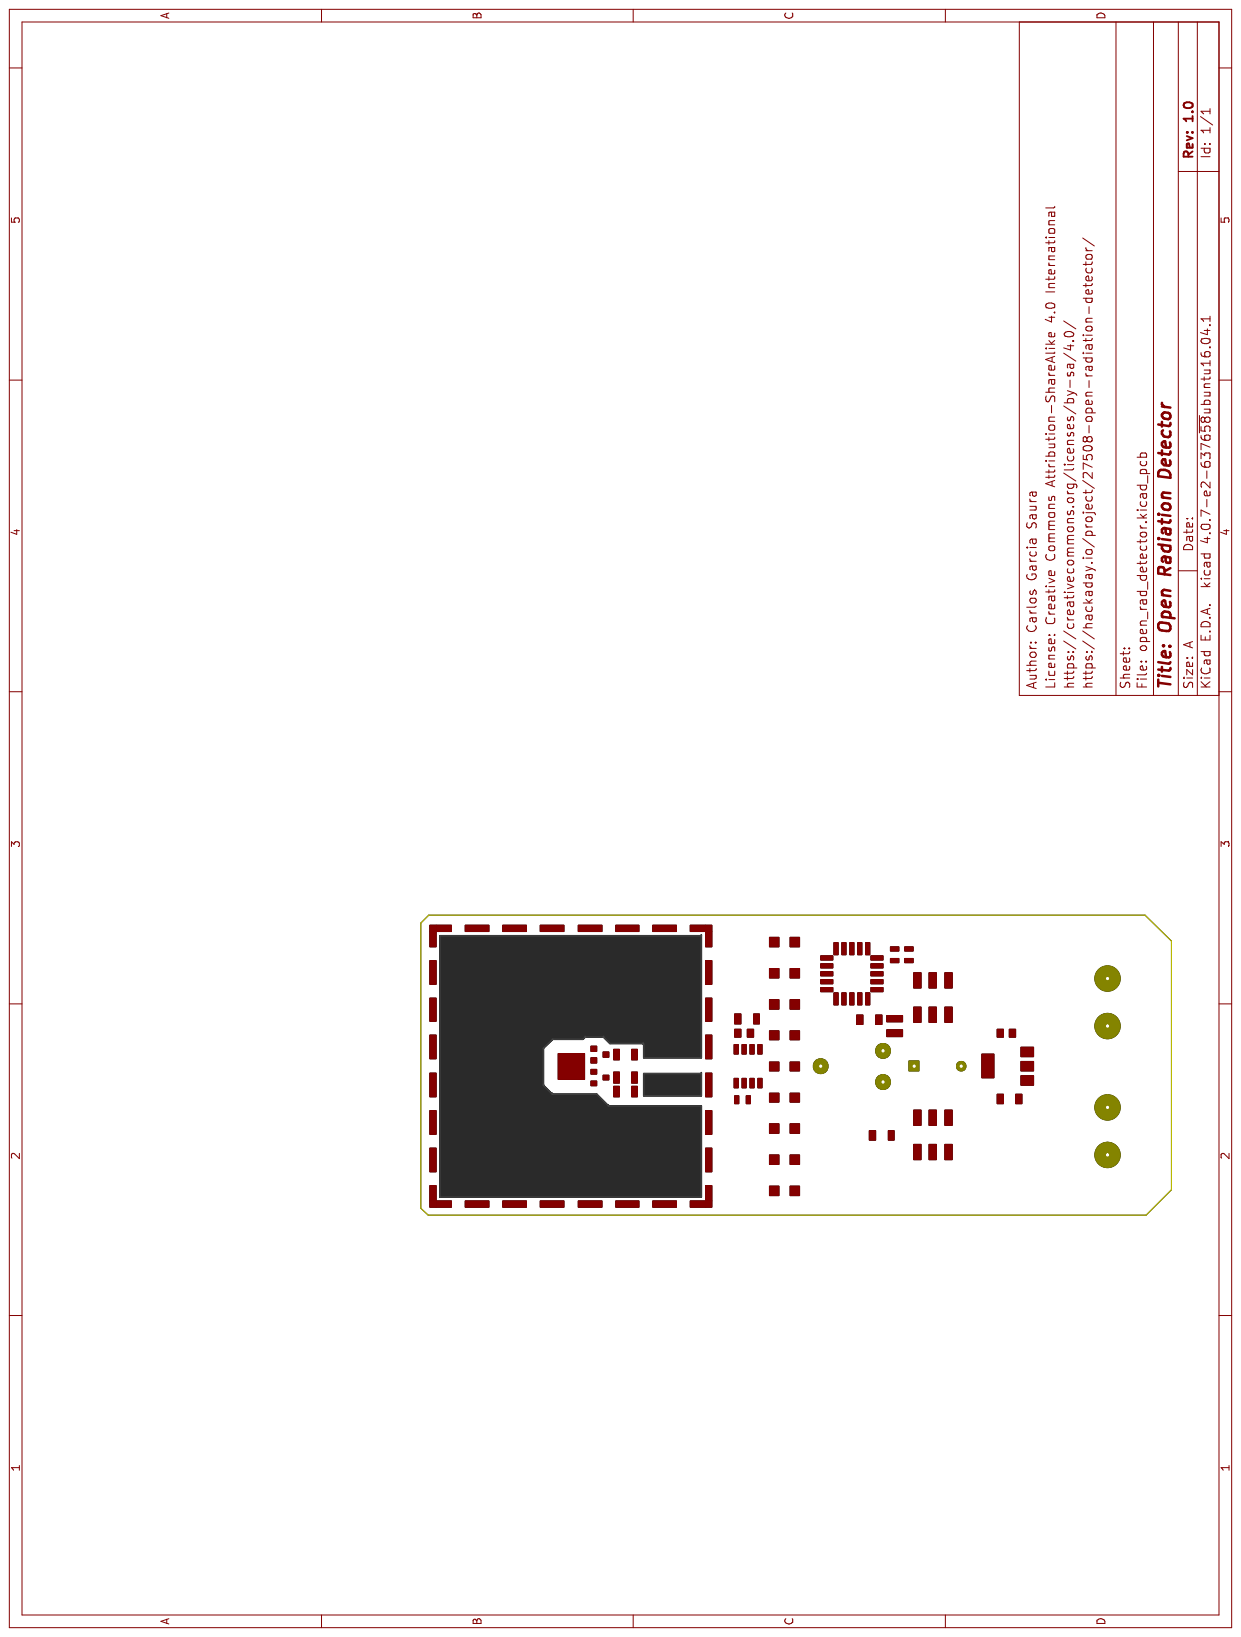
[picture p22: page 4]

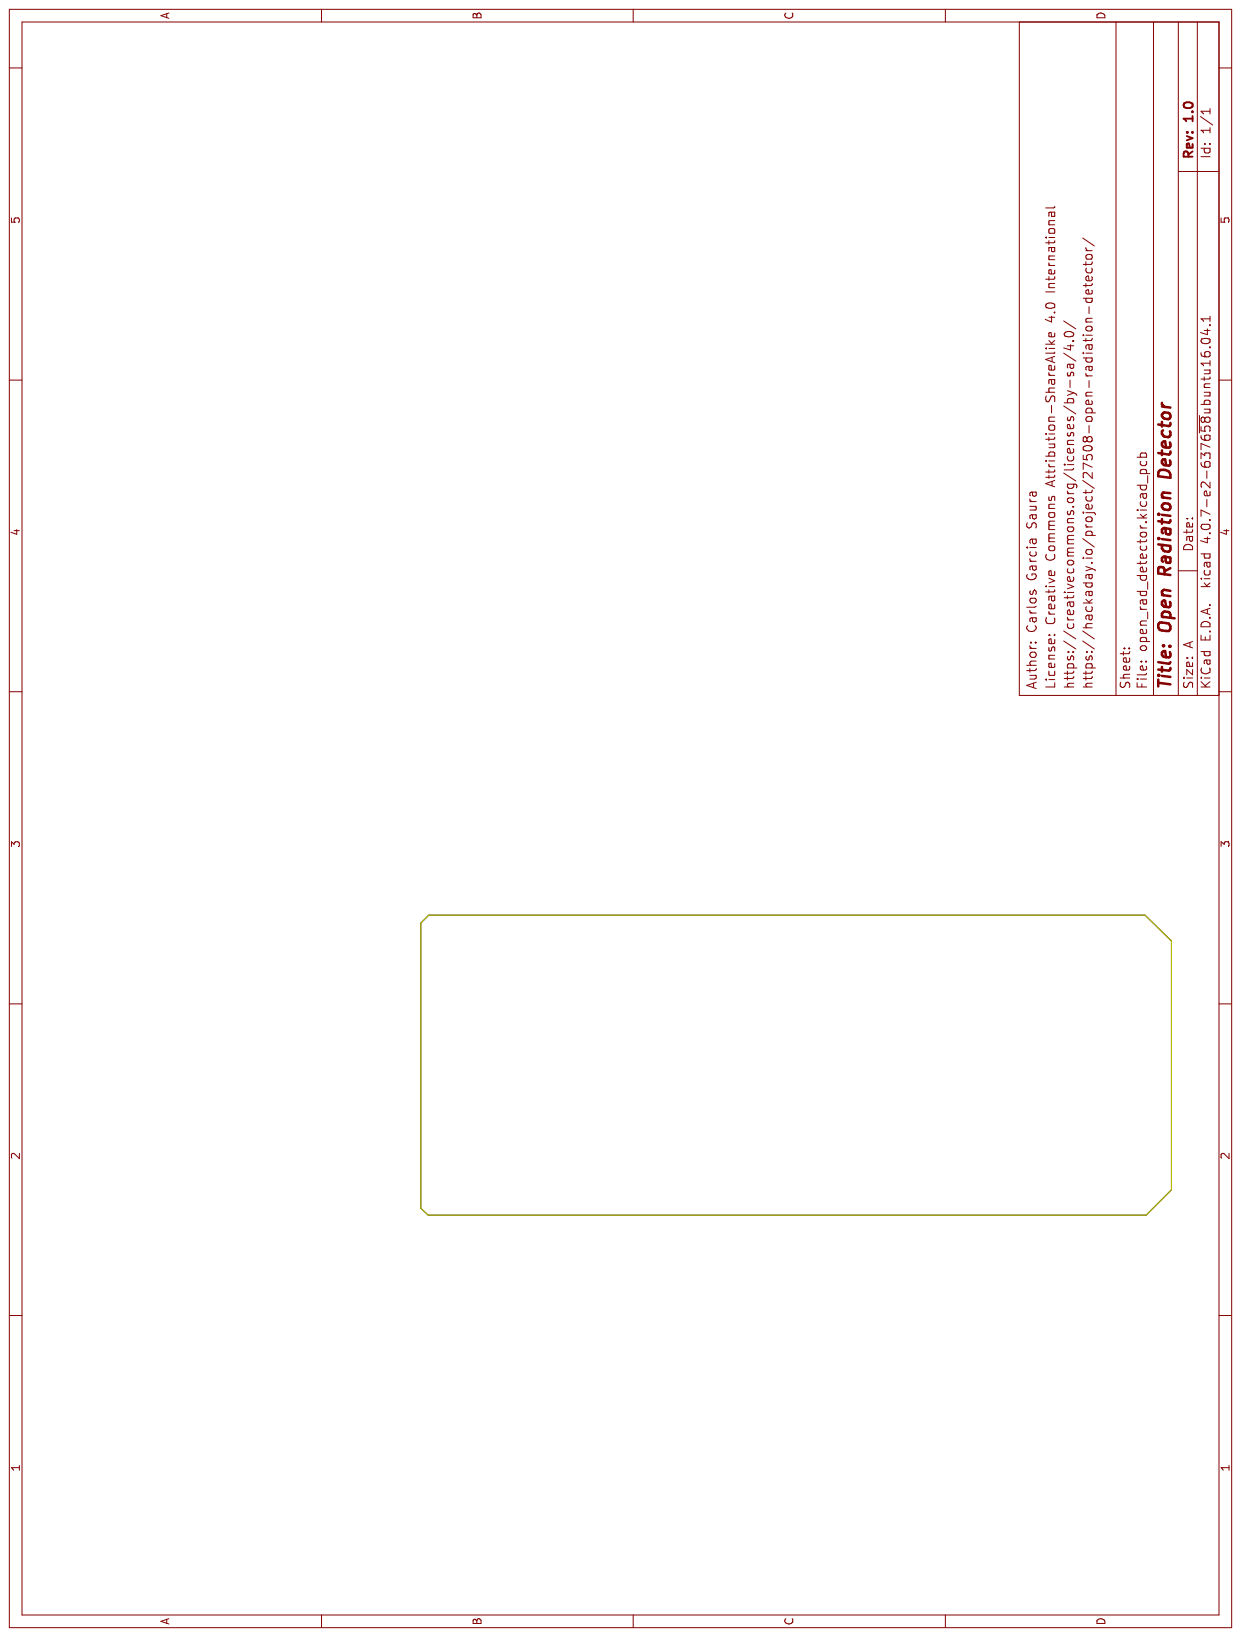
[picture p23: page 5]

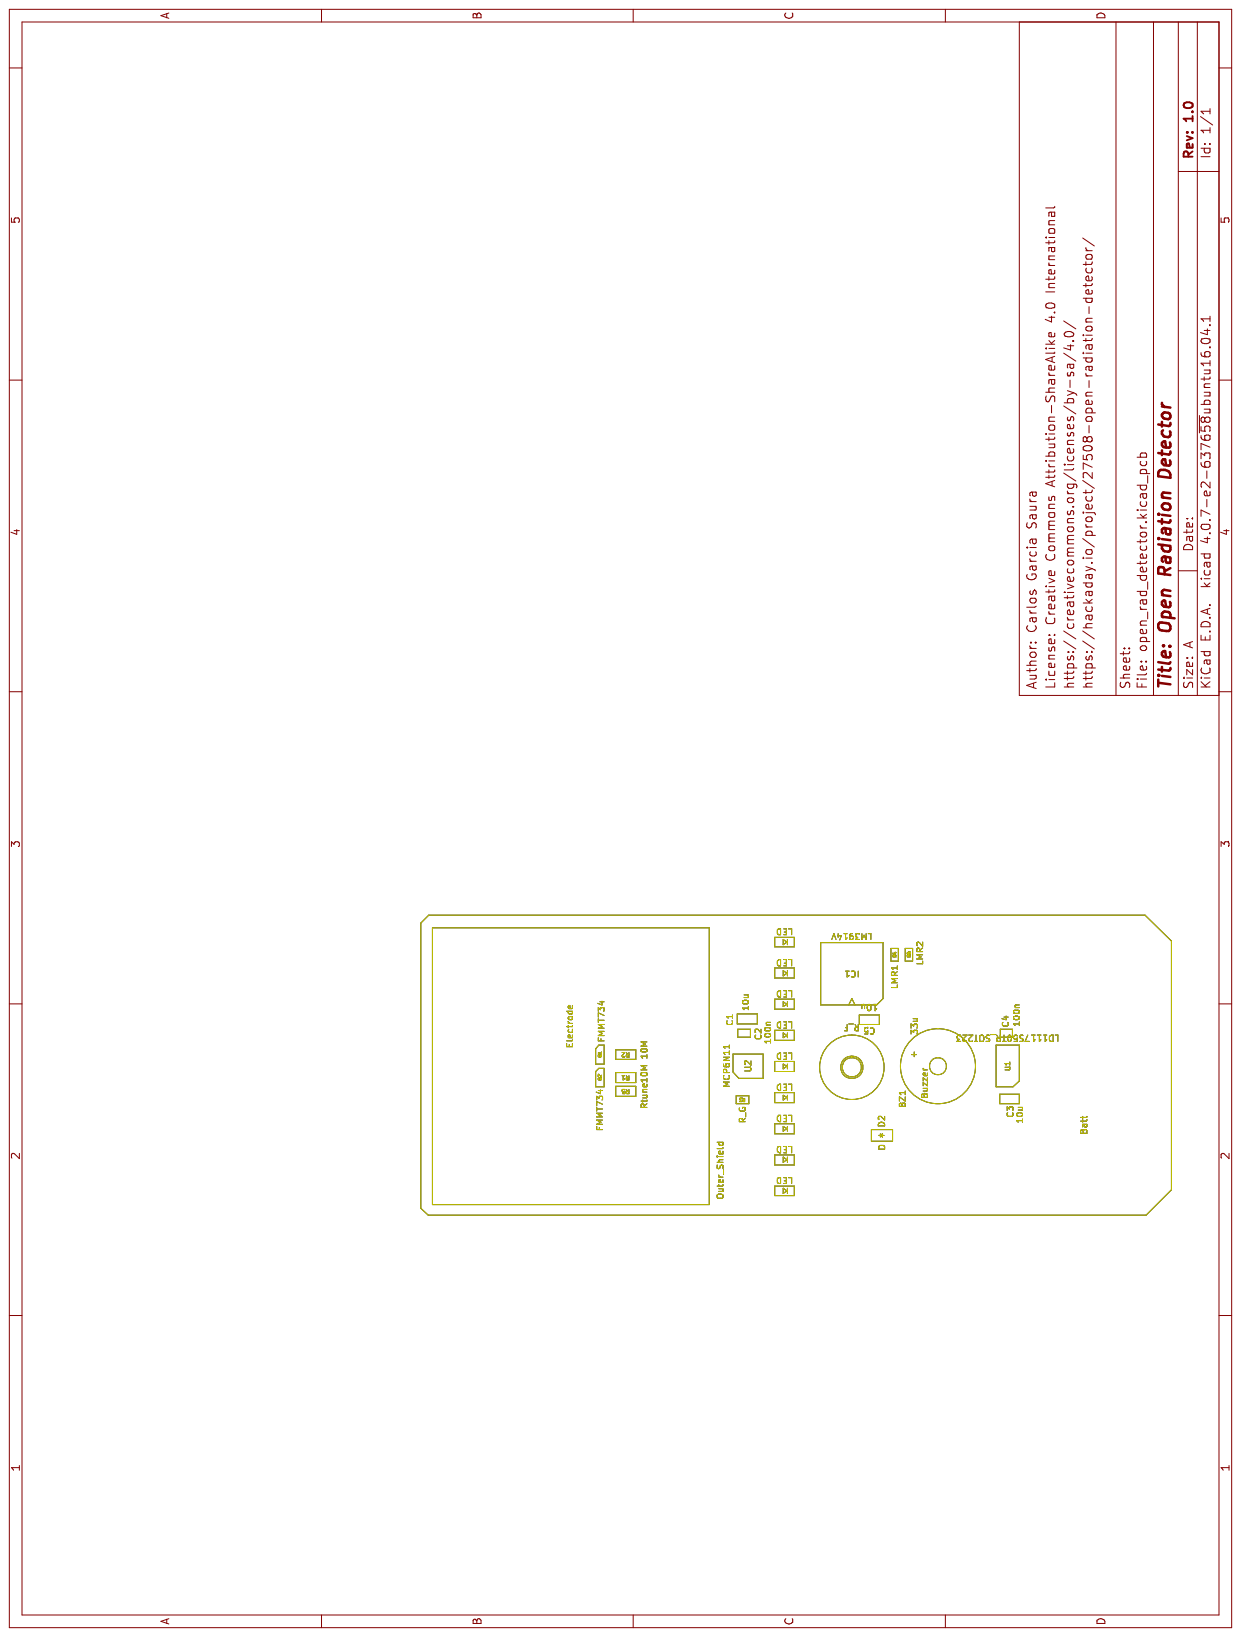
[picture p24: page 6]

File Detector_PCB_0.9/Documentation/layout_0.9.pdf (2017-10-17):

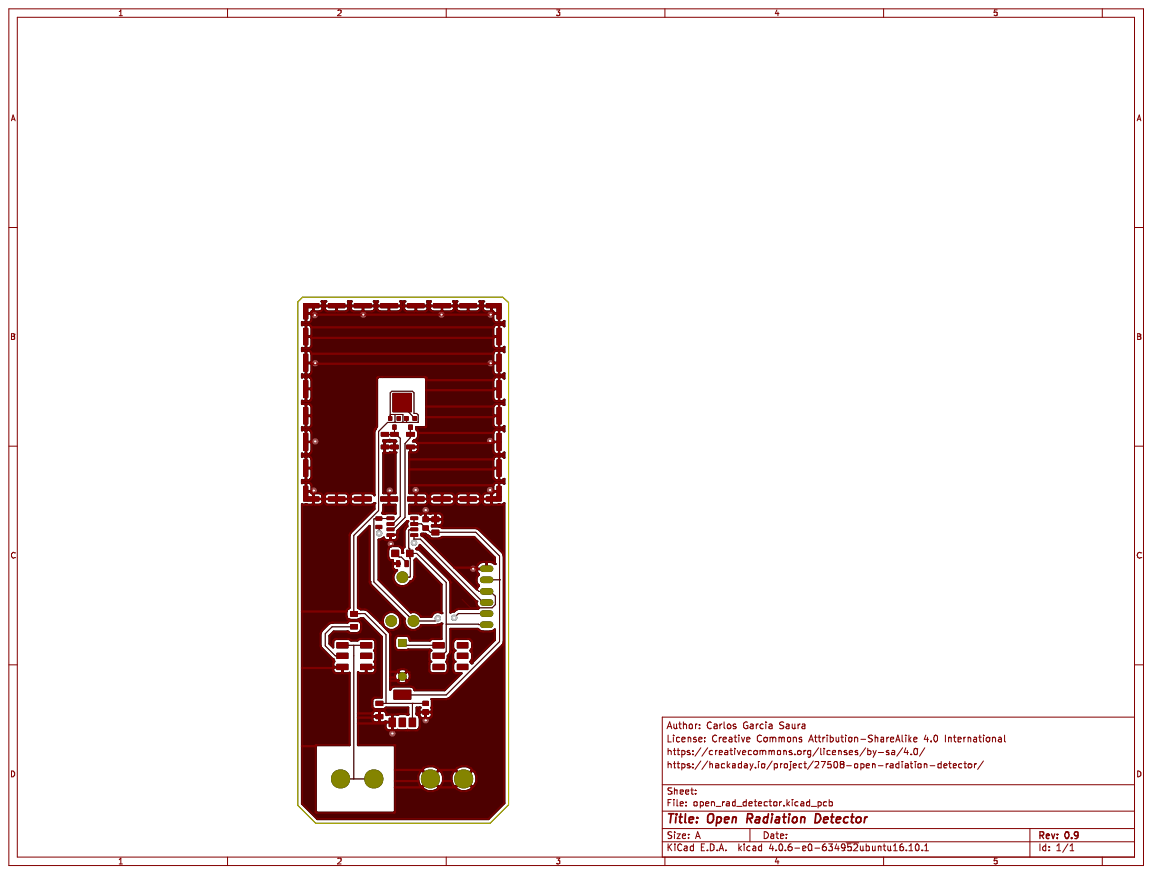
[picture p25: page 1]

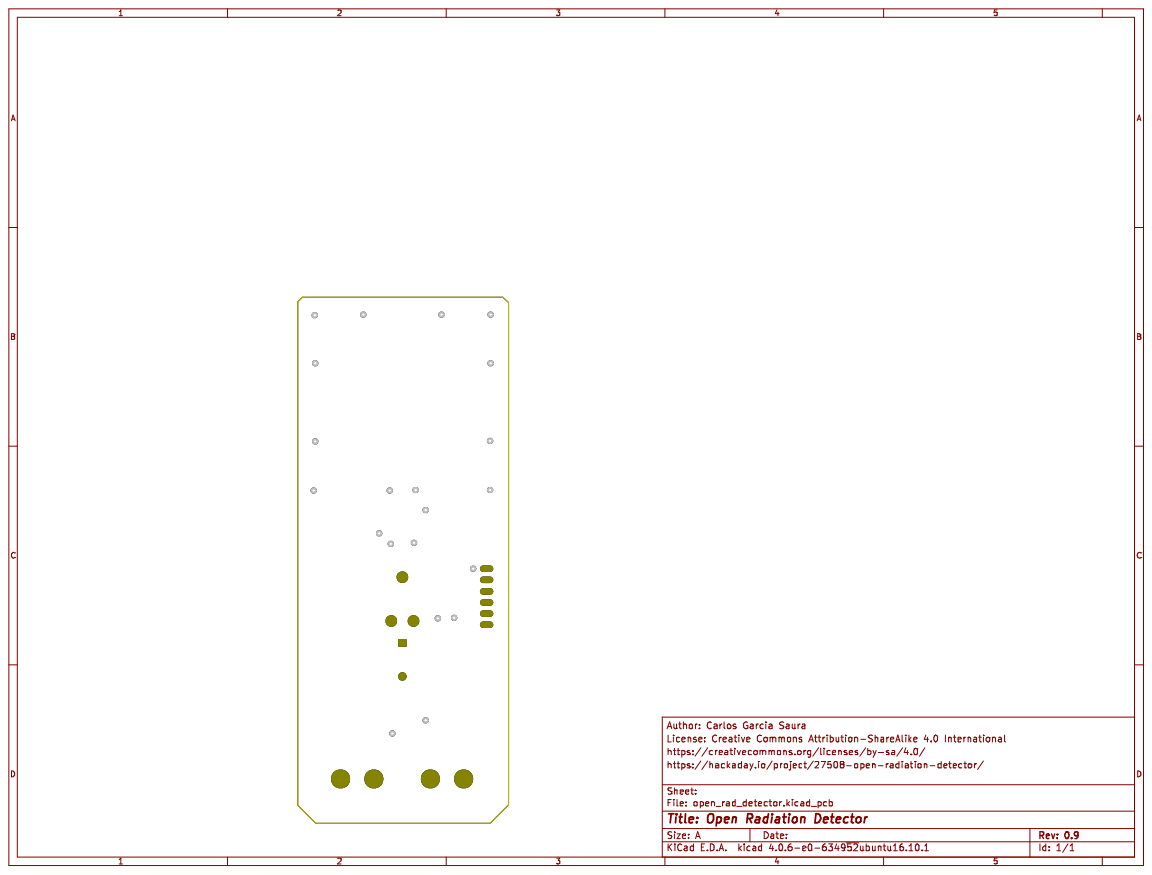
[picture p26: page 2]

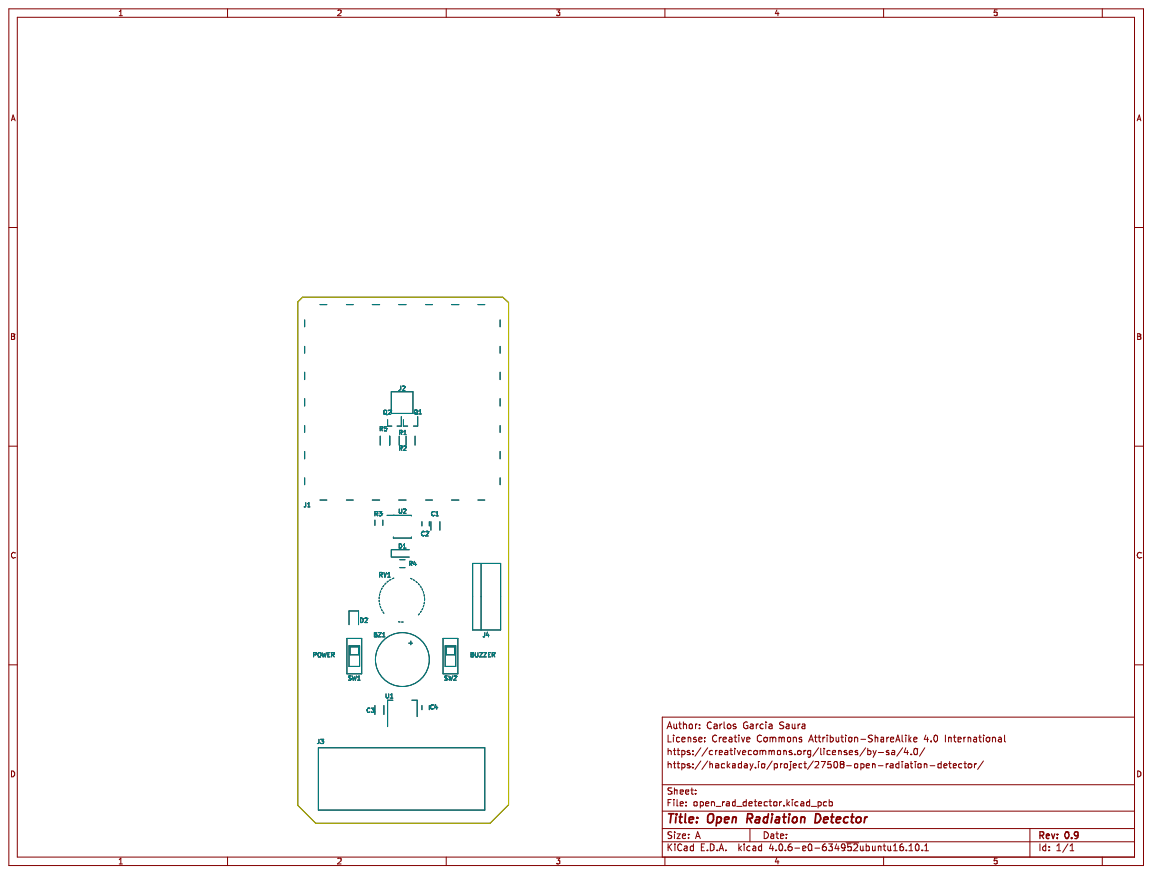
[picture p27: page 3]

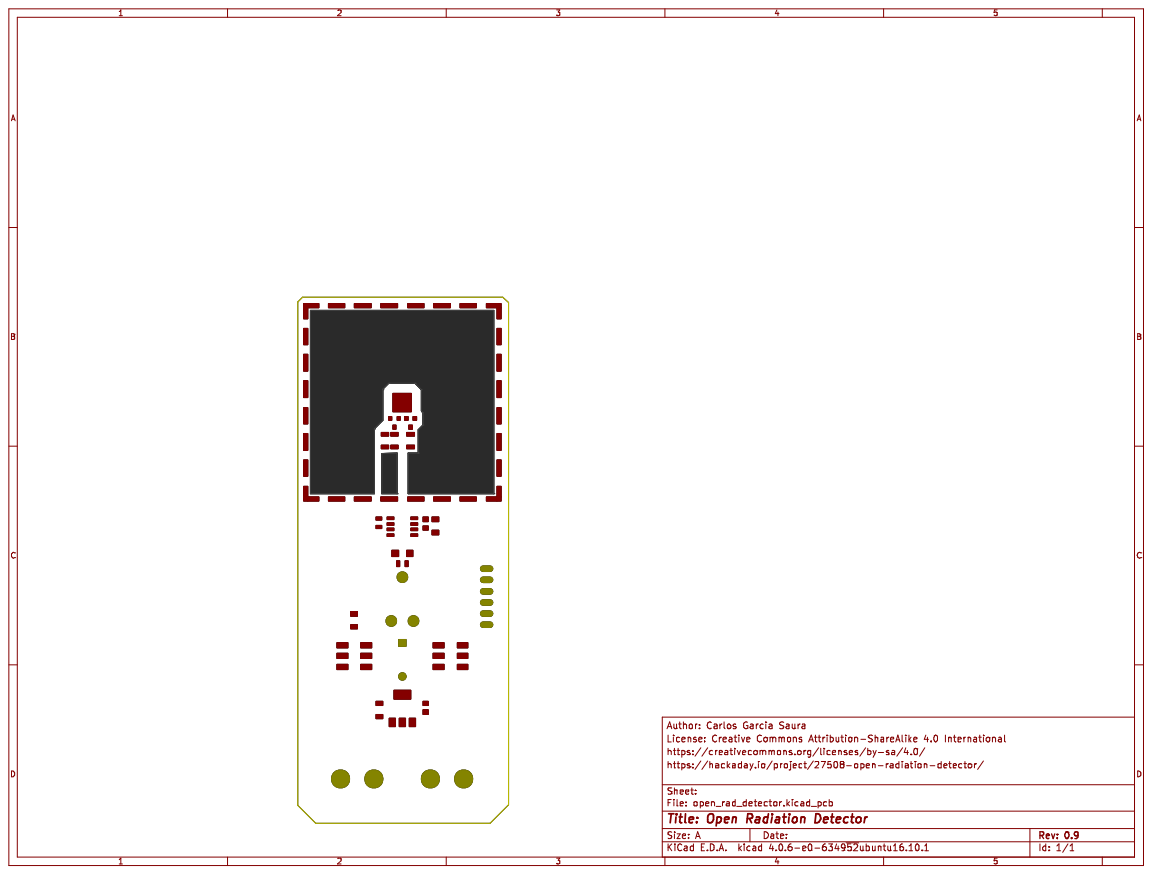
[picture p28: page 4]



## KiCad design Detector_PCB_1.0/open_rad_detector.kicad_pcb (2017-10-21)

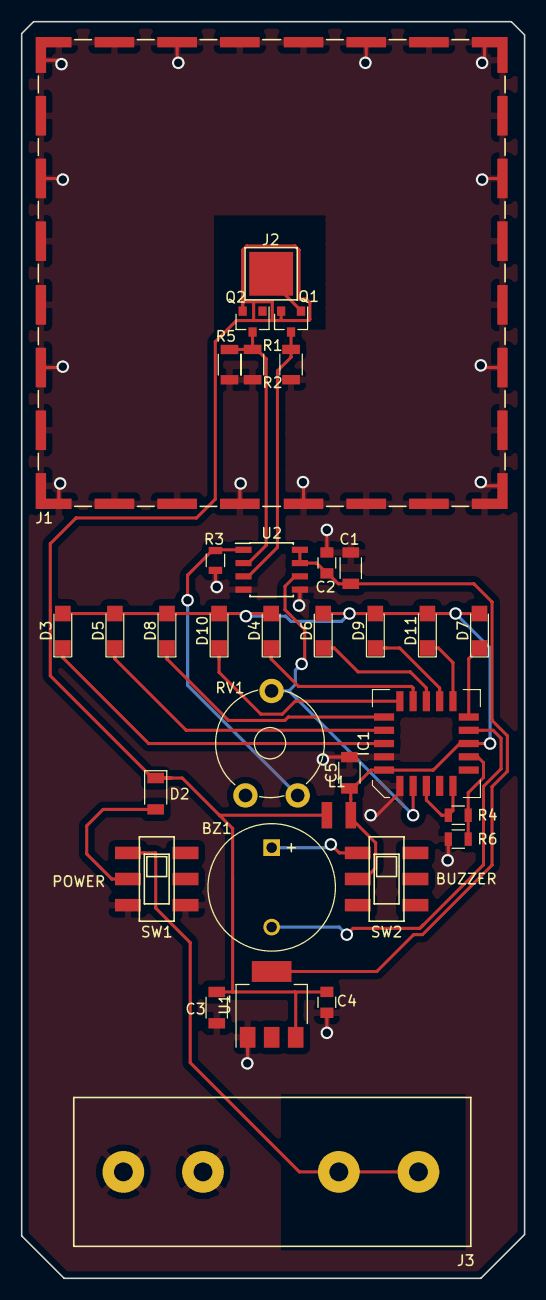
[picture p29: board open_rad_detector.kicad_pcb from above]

Board: 2 copper layers, 48.1 x 120.3 mm, 34 parts (0 on the bottom side), 24 nets.

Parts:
BZ1: Buzzer; MagneticBuzzer_ProSignal_ABI-010-RC
C1, C3, C5: 10u; C_1206
C2, C4: 100n; C_0805
D2: D; D_1206
D3, D4, D5, D6, D7, D8, D9, D10, D11: LED; LED_1206
IC1: LM3914V; PLCC-20
J1: Outer_Shield; Laird_Technologies_BMI-S-107_44.37x44.37mm
J2: Electrode; 1Pin
J3: Batt; A23_battery
L1: 33u; Neosid_Inductor_SM-NE29_SMD1008
Q1, Q2: FMMT734; SOT-23
R1, R2: 10M; R_1206
R3: R_G; R_0805
R4: LMR1; R_0805
R5: Rtune; R_1206
R6: LMR2; R_0805
RV1: R_F; Potentiometer_Trimmer_Piher_PT-10v10_Horizontal_Px10.0mm_Py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
SW1: POWER; SW_JS202011SCQN
SW2: BUZZER; SW_JS202011SCQN
U1: LD1117S50TR_SOT223; SOT-223-3_TabPin2
U2: MCP6N11; SOIC-8_3.9x4.9mm_Pitch1.27mm

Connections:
+5V: C1.1, C2.1, U1.2, U2.7, U2.8
+12V: C5.1, D3.2, D4.2, D5.2, D6.2, D7.2, D8.2, D9.2, D10.2, D11.2, IC1.3, IC1.11, L1.2, SW2.2
+BATT: C3.1, C4.1, D2.1, L1.1, Q1.2, Q2.2, U1.3
GND: C1.2, C2.2, C3.2, C4.2, C5.2, IC1.2, IC1.4, J1.1, J3.1, R1.2, R2.2, R3.2, R5.2, R6.2, SW1.3, U1.1, U2.4, U2.5
L1: D3.1, IC1.1
L2: D5.1, IC1.20
L3: D8.1, IC1.19
L4: D10.1, IC1.18
L5: D4.1, IC1.17
L6: D6.1, IC1.16
L7: D9.1, IC1.15
L8: D11.1, IC1.14
L9: D7.1, IC1.13
L10: BZ1.2, IC1.12
unnamed: BZ1.1, SW2.1
unnamed: D2.2, SW1.2
unnamed: IC1.6, IC1.8, R4.1
unnamed: IC1.10, R4.2, R6.1
unnamed: J2.1, Q1.1
unnamed: J3.2, SW1.1
v_comp: Q2.3, R1.1, R5.1, U2.2
v_fg: R3.1, RV1.1, U2.1
v_out: IC1.5, RV1.2, U2.6
v_rad: Q1.3, R2.1, U2.3

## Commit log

2017-10-17 Released version 0.9 of the detector
    [open_rad_detector.kicad_pcb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]
2017-10-17 Added BOM
    [BOM_open_rad_detector.ods]
2017-10-17 New version. Work in progress.
    [open_rad_detector.kicad_pcb, open_rad_detector.sch]
2017-10-17 Adapted to latest version of KiCad
    [BOM_open_rad_detector_0.9.ods, open_rad_detector.kicad_pcb, open_rad_detector.sch]
2017-10-17 Added LEDs
    [open_rad_detector.kicad_pcb, open_rad_detector.sch]
2017-10-18 Work in the new version
    [open_rad_detector.kicad_pcb, open_rad_detector.sch]
2017-10-18 Support latest KiCad version
    [open_rad_detector.kicad_pcb, open_rad_detector.sch]
2017-10-21 Added BOM and Gerbers for V1.0
    [BOM_open_rad_detector_0.9.ods, BOM_open_rad_detector_1.0.ods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]
